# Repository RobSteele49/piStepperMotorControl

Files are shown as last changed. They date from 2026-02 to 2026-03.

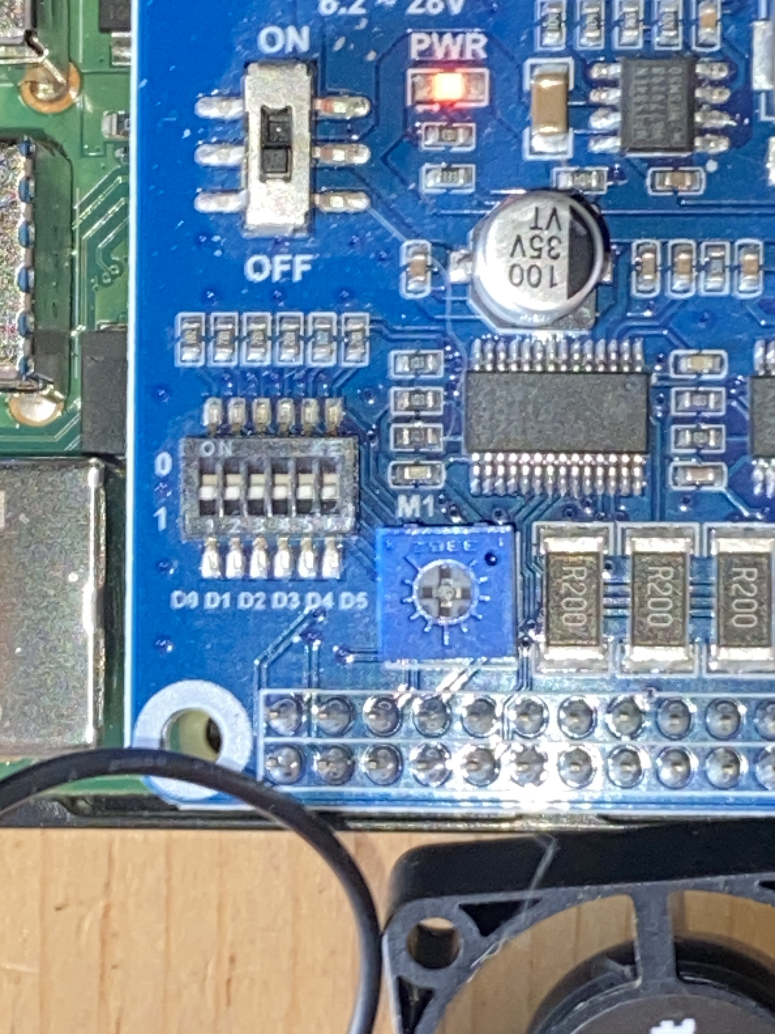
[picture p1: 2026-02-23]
photos/IMG_4501.JPG

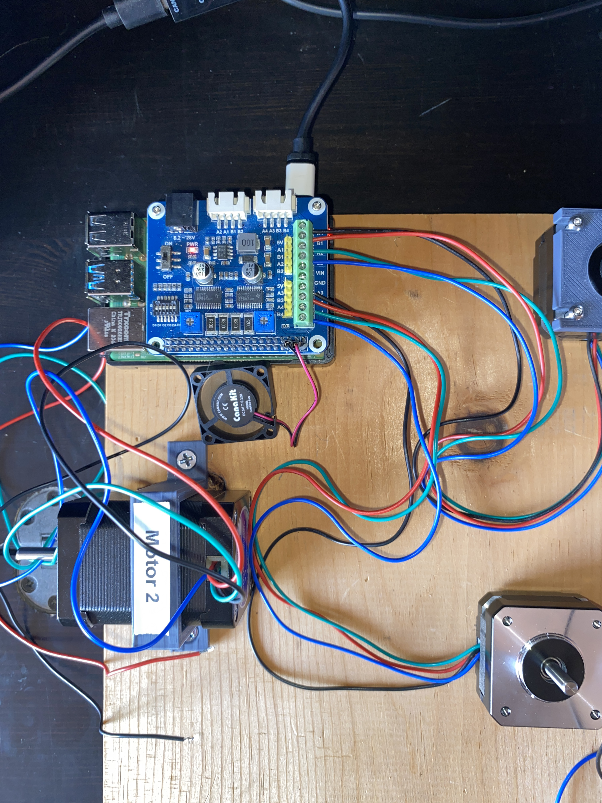
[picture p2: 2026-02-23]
photos/IMG_4499.JPG

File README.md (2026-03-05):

# piStepperMotorControl
Software for the controlling of steeper motors from a pi and pi hat.
Working software from across several directories will be placed here.

2026 03 05

Moved this document (and other project documents) into

- docs/ObsidianDocuments/ProjectDocuments to try and keep updated documents in a reasonable location.
- docs/ObsidianDocuments/Notes will be the home for notes before they get moved into more permanent locations or deleted.

2026 02 03

The code in this directory, with the DIP switches set to 1/16 step are working
for both motors are working.

The code provided by ChatGPT, which are NOT in this directory are NOT working.
I'm not sure why.

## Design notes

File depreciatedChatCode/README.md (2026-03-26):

Markdown
# piStepperMotorControl - LX200 Focuser & Rotator Automation

**Software for controlling stepper motors on a Raspberry Pi with LX200 protocol support and ASCOM Alpaca integration.**

This project provides automated control of focuser and rotator motors for telescope systems, featuring:
- **ASCOM Alpaca Server** for integration with astronomy software (NINA, etc.)
- **Physical button control** with speed ramping
- **Preset management** for saving/loading focus positions
- **Dual motor support** (focuser & rotator)
- **Watchdog protection** to prevent runaway motors
- **WaveShare stepper motor driver** support

---

## Table of Contents
- [Features](#features)
- [Hardware Requirements](#hardware-requirements)
- [Directory Structure](#directory-structure)
- [Installation](#installation)
- [Quick Start](#quick-start)
- [Architecture](#architecture)
- [Configuration](#configuration)
- [Usage](#usage)
- [Troubleshooting](#troubleshooting)
- [License](#license)

---

## Features

✅ **Dual Motor Control** - Independent focuser and rotator automation  
✅ **ASCOM Alpaca Protocol** - Seamless integration with NINA, APT, and other astronomy software  
✅ **Physical Button Interface** - 4-button control panel with speed ramping  
✅ **Preset Management** - Save and recall focus/rotator positions  
✅ **Safety Features** - Motor limits, watchdog timeout, emergency stop  
✅ **Network Accessible** - HTTP API on port 8080  
✅ **Low-Cost Hardware** - Uses standard Raspberry Pi and WaveShare stepper modules  

---

## Hardware Requirements

### Microcontroller
- **Raspberry Pi 3B+** or later (4B recommended for better performance)
- **Raspberry Pi OS** (Bullseye or later)

### Motor Control
- **2x WaveShare RS485 Stepper Motor Driver HAT** for each motor
- **2x NEMA17 Stepper Motors** (200 steps/rev)
- **Power Supply** - 12-24V @ 2A minimum per motor

### Physical Controls
- **4x Push Buttons** (momentary switches)
- **GPIO Pins**: 17, 27, 22, 23 (configurable in `config.h`)

### Wiring
Refer to the WaveShare motor driver documentation for GPIO pin mappings. The default configuration uses:
- GPIO 17: Focuser In
- GPIO 27: Focuser Out  
- GPIO 22: Rotator Clockwise
- GPIO 23: Rotator Counter-Clockwise

---

## Directory Structure

piStepperMotorControl/ ├── README.md # This file ├── CMakeLists.txt # CMake build configuration ├── include/ # Header files │ ├── AlpacaServer.hpp # ASCOM Alpaca HTTP server │ ├── WaveShareStepper.hpp # WaveShare driver interface │ └── config.h # System configuration constants ├── src/ # Source files │ ├── LX200_DualController.cpp # Main controller & UI │ ├── WaveShareStepper.cpp # Motor control implementation │ ├── AlpacaTest.cpp # Alpaca server test │ ├── HardwareProbe.cpp # Hardware diagnostics │ ├── testFocuser.cpp # Focuser unit tests │ ├── testRotator.cpp # Rotator unit tests │ └── httplib.h # HTTP library (header-only) ├── docs/ # Documentation │ ├── ObsidianDocuments/ # Project notes and specs │ └── ARCHITECTURE.md # (Coming soon) ├── photos/ # Hardware setup photos ├── CadFiles/ # 3D printing files for enclosure ├── build/ # Build output (auto-generated) └── CMakeLists.txt # Build configuration

Code

---

## Installation

### Prerequisites

1. **Update Raspberry Pi**
   ```bash
   sudo apt-get update
   sudo apt-get upgrade
Install Dependencies

bash
sudo apt-get install build-essential cmake git pigpio pigpio-tools
Enable I2C and SPI (required for WaveShare HAT)

bash
sudo raspi-config
# Navigate to Interface Options → I2C → Enable
# Navigate to Interface Options → SPI → Enable
Start pigpio daemon

bash
sudo systemctl enable pigpiod
sudo systemctl start pigpiod
Clone and Build
bash
# Clone the repository
git clone https://github.com/RobSteele49/piStepperMotorControl.git
cd piStepperMotorControl

# Create build directory
mkdir -p build
cd build

# Configure and compile
cmake ..
make

# Optional: Install to system
sudo make install
Quick Start
1. Configure Your Hardware
Edit include/config.h with your specific values:

C++
// Focuser travel range (steps)
const long long FOC_LIMIT_MIN = 0;
const long long FOC_LIMIT_MAX = 50000;

// Motor speeds (higher value = slower)
const int FOC_SPEED_MAX = 600;
const int FOC_SPEED_MED = 1200;
const int FOC_SPEED_SLOW = 2000;
2. Run the Controller
bash
cd build
./LX200_DualController
Output:

Code
=================== SYSTEM STATUS ======================
 FOCUSER: 25000 steps [50.0% Travel]
 ROTATOR: 0 steps [50.0% Travel]
 -------------------------------------------------------
 FOCUSER: [1-3] IN (0.1, 1, 5 Rev) | [4-6] OUT
 ROTATOR: [7] 1/16 CW | [8] 1/16 CCW
 PRESETS: [V] View/Apply | [K] Keep Current | [Y] Sync
 UTILS:   [G] GoTo  | [M] Move  | [R] Re-Seat | [L] Log
 POWER:   [U] Unlock Motors
 EXIT:    [P] Park & Log | [Q] Quit
3. Connect from NINA
Open NINA → Equipment → Add Device
Select Alpaca device type
Enter your Pi's IP address (default port 8080)
The "Dual Controller Focuser" and "Rotator" will appear
Architecture
Core Components
LX200_DualController (Main Controller)

Runs main event loop (50ms heartbeat)
Handles keyboard input, button presses, and menu navigation
Manages preset save/load
Coordinates with motor drivers
AlpacaServer (Network Interface)

Implements ASCOM Alpaca protocol over HTTP
Handles remote move commands from NINA, APT, etc.
Reports motor status (position, is_moving, etc.)
Runs in separate thread (port 8080)
WaveShareStepper (Motor Driver)

Interfaces with WaveShare RS485 HAT
Implements ramped acceleration/deceleration
Enforces soft limits (FOC_LIMIT_MIN/MAX, etc.)
Handles backlash compensation
Data Flow
Code
┌─────────────────────────────────────────────────────────┐
│         NINA / Astronomy Software                       │
│         (Remote Client)                                 │
└──────────────────────┬──────────────────────────────────┘
                       │ HTTP Requests
                       ▼
        ┌──────────────────────────────┐
        │   AlpacaServer (Thread)      │
        │   Port 8080                  │
        └──────────────┬───────────────┘
                       │
        ┌──────────────▼───────────────┐
        │  LX200_DualController        │
        │  Main Event Loop (50ms)      │
        └──────────┬──────────┬────────┘
                   │          │
        ┌──────────▼──┐  ┌────▼────────┐
        │  Focuser    │  │  Rotator    │
        │  WaveShare  │  │  WaveShare  │
        └─────────────┘  └─────────────┘
                   │          │
        ┌──────────▼──────────▼─┐
        │   GPIO / SPI / I2C    │
        │   Raspberry Pi HATs   │
        └───────────────────────┘
Session Logging
All motor movements are logged to night_log.txt:

Code
[2026-03-26 22:15] Foc:    25000 | Rot:        0
[2026-03-26 22:30] Foc:    30000 | Rot:      400
Configuration
Motor Speeds
Adjust these constants in config.h based on your motor and gearing:

C++
// Focuser (M1)
const int FOC_SPEED_MAX = 600;    // Fastest (600μs between steps)
const int FOC_SPEED_MED = 1200;   // Medium
const int FOC_SPEED_SLOW = 2000;  // Slowest

// Rotator (M2)
const int ROT_SPEED_MAX = 1600;
const int ROT_SPEED_MED = 2400;
const int ROT_SPEED_SLOW = 5000;
Lower values = faster motors. Adjust to prevent stalling.

Motor Limits
C++
// Focuser travel range
const long long FOC_LIMIT_MIN = 0;
const long long FOC_LIMIT_MAX = 50000;

// Rotator limits (prevents cable wrap)
const long long ROT_LIMIT_MIN = -6400;   // 2 full turns left
const long long ROT_LIMIT_MAX = 6400;    // 2 full turns right
Calibration
If your motor doesn't turn the expected distance:

Measure actual rotation: Run [K] (Keep Current) at a known position
Check STEPS_PER_KNOB_REV - currently calibrated for 5 turns → 6.75 turns
Recalibrate formula: STEPS_PER_KNOB_REV = (measured_steps / expected_steps) * current_value
Usage
Interactive Mode (Keyboard Control)
The program detects if it has a terminal and enters interactive mode:

Code
[1-3]  Move focuser IN  (0.1, 1.0, 5.0 revolutions)
[4-6]  Move focuser OUT
[7]    Rotate CW (1/16 turn)
[8]    Rotate CCW (1/16 turn)
[V]    View and apply presets
[K]    Keep current position as preset
[Y]    Sync motor to new position
[G]    Go to absolute position
[M]    Move by offset
[R]    Re-seat (backlash normalization)
[L]    View session log
[C]    Clear log
[U]    Unlock motors (release holding torque)
[P]    Park and exit
[Q]    Quit immediately
Physical Button Control
Press and hold buttons for adaptive speed:

< 2 seconds: Slow speed
> 2 seconds: Fast speed (ramping)
Service Mode (Background Operation)
If run without a terminal (e.g., from systemd):

bash
nohup ./LX200_DualController > /var/log/lx200.log 2>&1 &
The program will:

Skip the menu display
Still process physical buttons
Still respond to Alpaca network requests
Log all activity to night_log.txt
ASCOM Alpaca API
Available endpoints on http://<pi-ip>:8080:

Focuser Endpoints:

GET /api/v1/focuser/0/connected - Connection status
GET /api/v1/focuser/0/position - Current position
GET /api/v1/focuser/0/ismoving - Is motor moving?
PUT /api/v1/focuser/0/move?Position=<value> - Move to position
PUT /api/v1/focuser/0/halt - Stop immediately
Rotator Endpoints:

GET /api/v1/rotator/0/connected - Connection status
GET /api/v1/rotator/0/position - Current position
GET /api/v1/rotator/0/ismoving - Is motor moving?
PUT /api/v1/rotator/0/moveabsolute?Position=<value> - Move to position
PUT /api/v1/rotator/0/halt - Stop immediately
Troubleshooting
Motors Don't Move
 Check pigpiod is running: pgrep pigpiod
 Verify GPIO pins in config.h match your wiring
 Test with HardwareProbe utility
 Check motor power supply (12-24V)
 Ensure WaveShare HAT is properly connected
Alpaca Server Not Connecting
 Run from inside build/ directory
 Check firewall: sudo ufw allow 8080
 Verify Pi IP: hostname -I
 Test with browser: http://<pi-ip>:8080/management/v1/description
 Check network connectivity
Motors Skip Steps (Stalling)
 Reduce speed (increase delay value in config.h)
 Check power supply capacity
 Verify torque settings in WaveShare HAT DIP switches
 Check for mechanical binding
Position Drift
 Run [R] (Re-seat) to normalize backlash
 Check for loose gearing/belts
 Verify STEPS_PER_KNOB_REV calibration
 Check motor wiring for loose connections
Connection Timeout
 Increase watchdog timeout value in config.h
 Check system load with top
 Verify power supply under load
Development
Building Tests
bash
cd build
cmake -DBUILD_TESTS=ON ..
make
./testFocuser
./testRotator
Future Improvements
 Persistent position storage (EEPROM/database)
 Temperature monitoring
 Live position graphing
 Advanced backlash profiles
 Web UI dashboard
 Mobile app integration
License
© 2026 Robert D. Steele. All Rights Reserved.

Support
For issues, feature requests, or questions:

Check the Troubleshooting section
Review docs/ObsidianDocuments/ for detailed notes
Open an issue on GitHub
Last Updated: March 26, 2026
Version: 4.11

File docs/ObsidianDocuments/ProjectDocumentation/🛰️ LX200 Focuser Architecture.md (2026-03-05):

**Project:** Telescope Automation
**Platform:** Raspberry Pi + WaveShare Stepper HAT

## Component Breakdown
- **AlpacaServer.hpp:** The "Brain." Handles the ASCOM Alpaca REST API and translates network requests into motor commands.
- **WaveShareStepper.cpp/hpp:** The "Muscles." Low-level C++/pigpio code that manages step pulses, ramping, and power-save timeouts.
- **config.h:** The "Settings." Centralizes all hardware constants, speeds, and safety limits.
- **testFocuser.cpp:** The "Diagnostic." A standalone utility to verify mechanical calibration without needing ASCOM.

## Logic Flow
1. ASCOM (NINA) -> 2. REST API (Pi) -> 3. AlpacaServer -> 4. WaveShareStepper -> 5. GPIO Pulses -> 6. Motor

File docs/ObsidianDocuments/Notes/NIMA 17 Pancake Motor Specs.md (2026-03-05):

# Stepper Motor HAT for Raspberry Pi 4B/3B+/2B/B+/Zero/W/WH/and Jetson Nano,DRV8825 Motor Controller Drives Two Stepper Motors, Up to 1/32 Microstepping,Use for 3D Printer,Sculpturing Machine etc

| | |
|---|---|
|Brand|Bicool|
|Model Number|Stepper Motor HAT|
|Model Name|Stepper Motor HAT|
|Processor Brand|Broadcom|
|Video Processor|arm|
|UPC|779172279469|
|Manufacturer|Bicool|
|Best Sellers Rank|- #4,209 in [Single Board Computers (Computers & Accessories)](https://www.amazon.com/gp/bestsellers/pc/17441247011/ref=pd_zg_hrsr_pc)|
|ASIN|B08CCWDDQR|
|Customer Reviews|3.7 _3.7 out of 5 stars_   [(25)](https://www.amazon.com/dp/B08CCWDDQR?ref_=ppx_hzsearch_conn_dt_b_fed_asin_title_7#averageCustomerReviewsAnchor)|

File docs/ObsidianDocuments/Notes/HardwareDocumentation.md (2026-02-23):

**Computer Selection**

- Using a Raspberry Pi 4 for both the development and target environment.

**Motor Controller**

	- URL of Stepper Motor documentation:
		- https://www.waveshare.com/wiki/Stepper_Motor_HAT#Introduction
	- Additional pdf documentation available

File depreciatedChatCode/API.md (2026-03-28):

**Last Updated:** March 26, 2026  
**Version:** 1.0

Code

````

---

## **File 2: API.md**

```markdown
# ASCOM Alpaca API Reference

## Overview
The piStepperMotorControl system implements the ASCOM Alpaca protocol, enabling remote control from astronomy software like NINA, APT, SequenceGenerator Pro, and others.

## Connection Information

### Server Details
- **Host:** Your Raspberry Pi IP address (e.g., `192.168.1.100`)
- **Port:** `8080` (default)
- **Protocol:** HTTP
- **Base URL:** `http://<pi-ip>:8080`

### Finding Your Pi's IP Address
```bash
ssh pi@raspberrypi
hostname -I
````

Or from the Pi console:

bash

```
ip addr show | grep inet
```

---

## Management Endpoints

### Server Description

Returns information about the Alpaca server.

**Endpoint:**

Code

```
GET /management/v1/description
```

**Response:**

JSON

```
{
  "Value": {
    "ServerName": "Pi-LX200-Focuser",
    "Manufacturer": "Steele-Astronomy",
    "ManufacturerVersion": "1.1",
    "Location": "Observatory"
  },
  "ClientTransactionID": 0,
  "ServerTransactionID": 1,
  "ErrorNumber": 0,
  "ErrorMessage": ""
}
```

### Configured Devices

Returns list of available devices.

**Endpoint:**

Code

```
GET /management/v1/configureddevices
```

**Response:**

JSON

```
{
  "Value": [
    {
      "DeviceName": "Dual Controller Focuser",
      "DeviceType": "Focuser",
      "DeviceNumber": 0,
      "UniqueID": "Steele-Focuser-01"
    },
    {
      "DeviceName": "Dual Controller Rotator",
      "DeviceType": "Rotator",
      "DeviceNumber": 0,
      "UniqueID": "Steele-Rotator-01"
    }
  ],
  "ClientTransactionID": 0,
  "ServerTransactionID": 1,
  "ErrorNumber": 0,
  "ErrorMessage": ""
}
```

---

## Focuser Endpoints

### Connection Status

**Check if focuser is connected:**

Code

```
GET /api/v1/focuser/0/connected
PUT /api/v1/focuser/0/connected
```

**Parameters:** None for GET  
**PUT Body:** `Connected=true` or `Connected=false`

**Response:**

JSON

```
{
  "Value": true,
  "ClientTransactionID": 0,
  "ErrorNumber": 0,
  "ErrorMessage": ""
}
```

### Device Name

**Get focuser name:**

Code

```
GET /api/v1/focuser/0/name
```

**Response:**

JSON

```
{
  "Value": "Dual-Controller Focuser",
  "ClientTransactionID": 0,
  "ErrorNumber": 0,
  "ErrorMessage": ""
}
```

### Current Position

**Get current focuser position (in steps):**

Code

```
GET /api/v1/focuser/0/position
```

**Response:**

JSON

```
{
  "Value": 25000,
  "ClientTransactionID": 0,
  "ErrorNumber": 0,
  "ErrorMessage": ""
}
```

**Note:** Position is always in absolute steps from FOC_LIMIT_MIN.

### Movement Status

**Check if focuser is moving:**

Code

```
GET /api/v1/focuser/0/ismoving
```

**Response:**

JSON

```
{
  "Value": false,
  "ClientTransactionID": 0,
  "ErrorNumber": 0,
  "ErrorMessage": ""
}
```

Returns `true` while motor is moving, `false` when stationary.

### Absolute Position

**Check if focuser supports absolute positioning:**

Code

```
GET /api/v1/focuser/0/absolute
```

**Response:**

JSON

```
{
  "Value": true,
  "ClientTransactionID": 0,
  "ErrorNumber": 0,
  "ErrorMessage": ""
}
```

### Maximum Step Count

**Get maximum focuser position (max travel range):**

Code

```
GET /api/v1/focuser/0/maxstep
```

**Response:**

JSON

```
{
  "Value": 50000,
  "ClientTransactionID": 0,
  "ErrorNumber": 0,
  "ErrorMessage": ""
}
```

**Note:** This is set to `FOC_LIMIT_MAX` in config.h (typically 50000).

### Maximum Increment

**Get maximum single step distance:**

Code

```
GET /api/v1/focuser/0/maxincrement
```

**Response:**

JSON

```
{
  "Value": 5000,
  "ClientTransactionID": 0,
  "ErrorNumber": 0,
  "ErrorMessage": ""
}
```

**Note:** NINA uses this for safety checks. Adjustable in AlpacaServer.hpp.

### Move to Position

**Command focuser to absolute position:**

Code

```
PUT /api/v1/focuser/0/move
```

**Parameters:**

- `Position` (required) - Target position in steps (0 to 50000)
- `ClientTransactionID` (optional) - Tracking ID for your request

**Example:**

Code

```
PUT /api/v1/focuser/0/move?Position=30000&ClientTransactionID=1
```

**Response:**

JSON

```
{
  "ClientTransactionID": 1,
  "ErrorNumber": 0,
  "ErrorMessage": ""
}
```

**Important Notes:**

- Movement is asynchronous (returns immediately)
- Check `ismoving` endpoint to track completion
- Position will be clamped to FOC_LIMIT_MIN/MAX automatically

### Halt Movement

**Stop focuser immediately:**

Code

```
PUT /api/v1/focuser/0/halt
```

**Parameters:**

- `ClientTransactionID` (optional)

**Response:**

JSON

```
{
  "ClientTransactionID": 0,
  "ErrorNumber": 0,
  "ErrorMessage": ""
}
```

---

## Rotator Endpoints

### Connection Status

**Check if rotator is connected:**

Code

```
GET /api/v1/rotator/0/connected
PUT /api/v1/rotator/0/connected
```

**Response:** Same format as focuser

### Device Name

**Get rotator name:**

Code

```
GET /api/v1/rotator/0/name
```

**Response:**

JSON

```
{
  "Value": "Dual-Controller Rotator",
  "ClientTransactionID": 0,
  "ErrorNumber": 0,
  "ErrorMessage": ""
}
```

### Current Position

**Get current rotator position (in steps):**

Code

```
GET /api/v1/rotator/0/position
```

**Response:**

JSON

```
{
  "Value": 0,
  "ClientTransactionID": 0,
  "ErrorNumber": 0,
  "ErrorMessage": ""
}
```

**Note:** Position range is -6400 to +6400 steps (±2 full rotations).

### Movement Status

**Check if rotator is moving:**

Code

```
GET /api/v1/rotator/0/ismoving
```

**Response:** Same format as focuser

### Can Halt

**Check if rotator supports halt command:**

Code

```
GET /api/v1/rotator/0/canhalt
```

**Response:**

JSON

```
{
  "Value": true,
  "ClientTransactionID": 0,
  "ErrorNumber": 0,
  "ErrorMessage": ""
}
```

### Move to Absolute Position

**Command rotator to absolute angle:**

Code

```
PUT /api/v1/rotator/0/moveabsolute
```

**Parameters:**

- `Position` (required) - Target position in steps
- `ClientTransactionID` (optional)

**Example:**

Code

```
PUT /api/v1/rotator/0/moveabsolute?Position=1600&ClientTransactionID=2
```

**Response:**

JSON

```
{
  "ClientTransactionID": 2,
  "ErrorNumber": 0,
  "ErrorMessage": ""
}
```

**Important Notes:**

- Position will be clamped to ROT_LIMIT_MIN/MAX
- Movement is asynchronous
- 3200 steps = 1 full rotation

### Halt Movement

**Stop rotator immediately:**

Code

```
PUT /api/v1/rotator/0/halt
```

**Response:** Same format as focuser

---

## Integration Examples

### NINA (N.I.N.A.) Setup

1. **Open NINA Equipment Manager**
    
    - Go to Equipment → Add Device
    - Select "Alpaca" device type
    - Click "Search"
2. **Enter Connection Details**
    
    - Server: Your Pi's IP (e.g., 192.168.1.100)
    - Port: 8080
    - Click "Discover Devices"
3. **Select Devices**
    
    - Choose "Dual Controller Focuser"
    - Choose "Dual Controller Rotator"
    - Click "Add"
4. **Configure in NINA**
    
    - Set focuser as your active focuser
    - Set rotator as your active rotator
    - Configure autofocus settings

### Manual API Testing (cURL)

**Test connection:**

bash

```
curl http://192.168.1.100:8080/management/v1/description
```

**Move focuser to position 30000:**

bash

```
curl -X PUT "http://192.168.1.100:8080/api/v1/focuser/0/move?Position=30000"
```

**Get current focuser position:**

bash

```
curl http://192.168.1.100:8080/api/v1/focuser/0/position
```

**Rotate to 45 degrees (1/8 turn = 400 steps):**

bash

```
curl -X PUT "http://192.168.1.100:8080/api/v1/rotator/0/moveabsolute?Position=400"
```

**Stop all movement:**

bash

```
curl -X PUT http://192.168.1.100:8080/api/v1/focuser/0/halt
curl -X PUT http://192.168.1.100:8080/api/v1/rotator/0/halt
```

### Python Example

Python

```
import requests
import time

PI_IP = "192.168.1.100"
BASE_URL = f"http://{PI_IP}:8080"

# Move focuser to position 30000
response = requests.put(
    f"{BASE_URL}/api/v1/focuser/0/move",
    params={"Position": 30000}
)
print(f"Focuser move response: {response.json()}")

# Wait for movement to complete
while True:
    moving_response = requests.get(
        f"{BASE_URL}/api/v1/focuser/0/ismoving"
    )
    if not moving_response.json()["Value"]:
        break
    print("Moving...")
    time.sleep(0.5)

# Get final position
position_response = requests.get(
    f"{BASE_URL}/api/v1/focuser/0/position"
)
print(f"Final position: {position_response.json()['Value']}")

# Rotate
requests.put(
    f"{BASE_URL}/api/v1/rotator/0/moveabsolute",
    params={"Position": 1600}
)
```

---

## Error Handling

### Error Response Format

JSON

```
{
  "ClientTransactionID": 1,
  "ErrorNumber": 1,
  "ErrorMessage": "Position out of range"
}
```

### Common Error Codes

- **0** - No error
- **1** - Invalid parameter
- **2** - Device not connected
- **3** - Position out of range
- **999** - Driver error

### Error Scenarios

**Position out of range:**

- Attempting to move beyond FOC_LIMIT_MIN/MAX or ROT_LIMIT_MIN/MAX
- System automatically clamps to valid range

**Device not connected:**

- Motor driver not responding
- Check power supply and wiring
- Verify pigpiod daemon is running

---

## Response Format Specification

All responses follow ASCOM Alpaca standard:

JSON

```
{
  "Value": <any>,                    // Response data (varies by endpoint)
  "ClientTransactionID": <number>,   // Echo of client's request ID
  "ServerTransactionID": <number>,   // Server's transaction sequence
  "ErrorNumber": <number>,           // 0 = success, non-zero = error
  "ErrorMessage": "<string>"         // Error description (empty if success)
}
```

---

## Performance Characteristics

### Response Times

- **Status queries** (position, ismoving): < 50ms
- **Move commands** (async): < 100ms
- **Network latency** (local network): 1-10ms

### Movement Profiles

- **Typical focus move** (10,000 steps): 3-5 seconds
- **Full rotation** (3200 steps): 2-4 seconds
- **Speed adjustable** via config.h

### Concurrent Requests

- Focuser and rotator can move simultaneously
- Each has independent movement queue
- Requests are processed in order

---

## Debugging & Testing

### Test Server Availability

bash

```
curl -v http://<pi-ip>:8080/management/v1/description
```

### Monitor Real-Time Logs

bash

```
ssh pi@raspberrypi
tail -f night_log.txt
```

### Enable Debug Output

In `AlpacaServer.hpp`, uncomment debug statements:

C++

```
std::cout << "[NET] Focuser Move Threaded -> " << target << std::endl;
```

---

## Best Practices

1. **Always check `ismoving` before issuing new commands**
    
    Python
    
    ```
    while requests.get(f"{BASE_URL}/api/v1/focuser/0/ismoving").json()["Value"]:
        time.sleep(0.1)
    ```
    
2. **Use reasonable position increments**
    
    - Large jumps (> 10000 steps) risk mechanical shock
    - Use MaxIncrement (5000 steps) as guidance
3. **Implement connection retry logic**
    
    Python
    
    ```
    import time
    for attempt in range(3):
        try:
            response = requests.get(f"{BASE_URL}/management/v1/description", timeout=2)
            if response.status_code == 200:
                break
        except:
            time.sleep(1)
    ```
    
4. **Log all movements for troubleshooting**
    
    - Check `night_log.txt` on the Pi
    - Correlate with your observation timeline
5. **Halt before critical operations**
    
    Python
    
    ```
    requests.put(f"{BASE_URL}/api/v1/focuser/0/halt")
    requests.put(f"{BASE_URL}/api/v1/rotator/0/halt")
    time.sleep(0.5)
    ```

---

## Limitations & Known Issues

- Movement is asynchronous (no blocking calls)
- No intermediate position updates during movement
- No acceleration/deceleration feedback
- Position accuracy depends on STEPS_PER_KNOB_REV calibration
- Network timeout if Pi loses power/connectivity

---

## Troubleshooting

### "Connection refused" on port 8080

- Verify Pi is running and network is available
- Check firewall: `sudo ufw allow 8080`
- Restart service: `pkill LX200_DualController`

### NINA can't discover devices

- Ensure Alpaca server is running
- Verify IP address and port are correct
- Check that Pi is on same network as NINA machine

### Movements are very slow

- Check config.h motor speed settings
- Verify power supply is adequate (12-24V @ 2A)
- Run calibration test

### Position doesn't reach target

- Verify position is within limits
- Check for mechanical binding
- Run re-seat operation via CLI: `[R]`

---

## API Changelog

### Version 3.0 (Current)

- Full ASCOM Alpaca protocol support
- Improved connection handshaking
- MaxStep and MaxIncrement endpoints
- Better error handling

### Version 2.0

- Basic HTTP server
- Core move commands

### Version 1.0

- Initial release

---

## Additional Resources

- [ASCOM Alpaca Specification](https://ascom-standards.org/Help/Platform/html/T_ASCOM_Alpaca_Discovery.htm)
- [NINA Documentation](https://nighttime-imaging.eu/)
- Project README: [README.md](https://github.com/README.md)
- Configuration Guide: [CONFIGURATION.md](https://github.com/copilot/c/CONFIGURATION.md)

---

**Last Updated:** March 26, 2026  
**API Version:** 3.0  
**Server Version:** 4.11

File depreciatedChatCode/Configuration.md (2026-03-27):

````
# Configuration Guide

## Overview
This guide provides detailed information on configuring the piStepperMotorControl system for your specific telescope setup and hardware.

## Configuration File Location
All configuration constants are defined in: `include/config.h`

---

## Hardware Settings

### Microstepping Configuration
```cpp
const int STEPS_PER_REV = 3200;         // 200 * 16 (1/16 microstepping)
const int DEFAULT_RAMP_MS = 800;        // Default ramp time in milliseconds
const int STEPS_PER_KNOB_REV = 2480;    // Calibrated steps per physical revolution
````

**Note:** The `STEPS_PER_KNOB_REV` value is calibrated for your specific gearing. The current value assumes 5 commanded turns result in 6.75 actual turns. Adjust this if your motor behavior differs.

---

## Focuser Configuration

### Travel Limits

C++

```
const long long FOC_LIMIT_MIN = 0;           // Minimum position (steps)
const long long FOC_LIMIT_MAX = 50000;       // Maximum position (steps)
```

**How to Set:**

1. Manually move your focuser to the closest focus position
2. Record the position value shown in the UI
3. Set `FOC_LIMIT_MIN` to this value
4. Move to the furthest focus position
5. Set `FOC_LIMIT_MAX` to this value
6. Recompile with `cmake .. && make`

### Motor Speed Configuration

C++

```
// FOCUSER (M1) - Delays in microseconds between steps
const int FOC_SPEED_MAX = 600;          // Fastest (less delay = faster)
const int FOC_SPEED_MED = 1200;         // Medium speed
const int FOC_SPEED_SLOW = 2000;        // Slowest (more delay = slower)
const int FOC_BACKLASH = 600;           // Backlash compensation (steps)
const int FOC_PREF_DIR = 0;             // Preferred direction (0=CCW, 1=CW)
```

**Speed Tuning Guide:**

- **Speed value** = delay in microseconds between motor steps
- **Smaller value** = Motor moves faster (shorter delays)
- **Larger value** = Motor moves slower (longer delays)
- **Recommended range:** 500-3000

**If motor stalls:**

- Increase the speed value (e.g., FOC_SPEED_MAX from 600 to 800)
- Check power supply voltage under load
- Verify motor wiring

**If motor moves too slowly:**

- Decrease the speed value (e.g., FOC_SPEED_MED from 1200 to 1000)
- Ensure power supply can deliver full current

### Backlash Compensation

C++

```
const int FOC_BACKLASH = 600;           // Steps to overshoot and return
```

The backlash compensation works by:

1. Moving beyond target by `FOC_BACKLASH` steps
2. Moving backward to actual target
3. Eliminates gear slack

**Tuning:**

- If focus still drifts: increase value (try 800-1000)
- If overshoot causes issues: decrease value (try 400-500)

---

## Rotator Configuration

### Travel Limits

C++

```
const long long ROT_LIMIT_MIN = -6400;   // 2 full turns left (prevents cable wrap)
const long long ROT_LIMIT_MAX = 6400;    // 2 full turns right
```

**Why these limits?**

- Prevents cable tangling
- Limits continuous rotation to ±2 full turns
- Adjust based on your cable management setup

### Motor Speed Configuration

C++

```
// ROTATOR (M2) - Delays in microseconds between steps
const int ROT_SPEED_MAX = 1600;         // Fastest
const int ROT_SPEED_MED = 2400;         // Medium speed
const int ROT_SPEED_SLOW = 5000;        // Slowest
const int ROT_BACKLASH = 200;           // Backlash compensation (steps)
const int ROT_PREF_DIR = 1;             // Preferred direction (0=CCW, 1=CW)
```

**Note:** Rotator speeds are slower than focuser because rotation is more critical for precision. Fine adjustments may be needed for your specific camera/filter setup.

---

## Button Control Configuration

### GPIO Pin Assignment

C++

```
// BUTTON BOX PINS (GPIO Numbers on Raspberry Pi)
const int BTN_FOC_IN = 17;      // Focuser move IN (toward scope)
const int BTN_FOC_OUT = 27;     // Focuser move OUT (away from scope)
const int BTN_ROT_CW = 22;      // Rotator Clockwise
const int BTN_ROT_CCW = 23;     // Rotator Counter-Clockwise
```

**GPIO Pin to Physical Pin Mapping:**

Code

```
GPIO 17 → Pin 11
GPIO 27 → Pin 13
GPIO 22 → Pin 15
GPIO 23 → Pin 16
```

### Speed Ramping Configuration

C++

```
const double RAMP_THRESHOLD_SEC = 2.0;  // Seconds before switching to high speed
```

**How it works:**

- **Button pressed < 2 seconds:** Uses SLOW speed setting
- **Button held > 2 seconds:** Switches to MAX speed setting
- **Adjustment:** Change 2.0 to different value (e.g., 1.5 or 3.0) for different threshold

---

## Re-seating (Backlash Normalization)

### Configuration

C++

```
#define RESEAT_GAP_STEPS 1000  // Distance to move for backlash elimination
```

**What is Re-seating?**

- Moves motor forward by `RESEAT_GAP_STEPS`
- Then moves back to original position
- Eliminates accumulated backlash

**When to use:**

- After initial setup
- Before important observations
- If you notice position drift
- Press `[R]` in interactive mode

**Tuning `RESEAT_GAP_STEPS`:**

- **Too small (< 500):** Doesn't eliminate backlash effectively
- **Too large (> 2000):** Time-consuming and unnecessary
- **Recommended:** 800-1200 for focuser, 400-800 for rotator

---

## Motor Calibration

### STEPS_PER_KNOB_REV Calculation

This value represents how many steps are needed for one physical revolution of your knob/gearing.

**Calibration Procedure:**

1. **Initial Measurement:**
    
    C++
    
    ```
    const int STEPS_PER_KNOB_REV = 2480;  // Current value
    ```
    
2. **Command Test Movement:**
    
    - Use menu option `[K]` to record starting position
    - Then move using menu option `[1]` (0.1 revolution)
    - Note the steps moved
3. **Calculate Actual Ratio:**
    
    Code
    
    ```
    Expected steps = 2480 * 0.1 = 248 steps
    If actual moved = 300 steps:
    New STEPS_PER_KNOB_REV = 2480 * (300/248) = 3000
    ```
    
4. **Update and Recompile:**
    
    C++
    
    ```
    const int STEPS_PER_KNOB_REV = 3000;  // Updated value
    ```
    
    Then: `cd build && cmake .. && make`

### Mechanical Calibration Checklist

- [ ]  Verify motor is mechanically coupled to focuser
- [ ]  Check for loose belts or gears
- [ ]  Test smooth motion in both directions
- [ ]  Verify power supply voltage: 12-24V DC
- [ ]  Check motor wiring for corrosion

---

## Advanced Configuration

### Preset Management

Presets are automatically saved to `presets.txt` in the working directory.

**Preset Format:**

Code

```
PresetName1 position_focuser position_rotator
PresetName2 position_focuser position_rotator
```

**Example:**

Code

```
Sharp 25000 0
SlightlyOut 27000 0
Rotated45deg 25000 1600
```

### Session Logging

All motor movements are logged to `night_log.txt`:

Code

```
[2026-03-26 22:15] Foc:    25000 | Rot:        0
[2026-03-26 22:30] Foc:    30000 | Rot:      400
[2026-03-26 22:45] Foc:    28500 | Rot:      400
```

To clear logs, press `[C]` in interactive mode.

---

## Recommended Configuration Examples

### Example 1: Refractor Scope (Slow, Precise Movement)

C++

```
// Use slower speeds for fine adjustments
const int FOC_SPEED_MAX = 1000;
const int FOC_SPEED_MED = 1500;
const int FOC_SPEED_SLOW = 2500;

// Increase backlash compensation
const int FOC_BACKLASH = 800;
```

### Example 2: Newtonian Reflector (Fast Movement)

C++

```
// Use faster speeds for quick adjustments
const int FOC_SPEED_MAX = 400;
const int FOC_SPEED_MED = 800;
const int FOC_SPEED_SLOW = 1500;

// Smaller backlash compensation
const int FOC_BACKLASH = 400;
```

### Example 3: Large Dobsonian (High Backlash)

C++

```
// Compensate for mechanical slack
const int FOC_BACKLASH = 1200;
const int RESEAT_GAP_STEPS = 1500;

// Slower, controlled movement
const int FOC_SPEED_MAX = 800;
const int FOC_SPEED_MED = 1200;
```

---

## Testing Configuration Changes

After modifying `config.h`:

bash

```
cd build
cmake ..
make
./LX200_DualController
```

**Functional Tests:**

1. Press `[1]` - Verify focuser moves IN the expected distance
2. Press `[7]` - Verify rotator moves CW smoothly
3. Press `[K]` - Save current position as preset
4. Press `[V]` - Retrieve and verify preset
5. Press `[R]` - Run re-seating operation

---

## Troubleshooting Configuration

### Problem: Motor Stalls During Movement

**Solution:**

- Increase speed value (e.g., FOC_SPEED_MAX: 600 → 800)
- Check power supply: should be 12-24V @ 2A min
- Verify motor wiring is secure
- Test with HardwareProbe utility

### Problem: Motor Overshoots Target Position

**Solution:**

- Decrease speed value (e.g., FOC_SPEED_MAX: 600 → 400)
- Increase backlash value (FOC_BACKLASH: 600 → 800)
- Run re-seating more frequently

### Problem: Position Drifts Over Time

**Solution:**

- Run re-seating: Press `[R]` periodically
- Increase backlash compensation
- Check for mechanical issues (loose gears, belts)
- Recalibrate STEPS_PER_KNOB_REV

### Problem: Buttons Don't Respond

**Solution:**

- Verify GPIO pins match physical wiring
- Check pull-up resistors on button circuit
- Test with `HardwareProbe` utility
- Check pigpiod is running: `pgrep pigpiod`

---

## Safety Considerations

### Motor Limits

The soft limits prevent mechanical damage:

C++

```
const long long FOC_LIMIT_MIN = 0;
const long long FOC_LIMIT_MAX = 50000;
```

**Always:**

- Set realistic limits for your hardware
- Test limits before nighttime observing
- Verify motors stop at boundaries

### Watchdog Timeout

Motors automatically cut power after 30 seconds of no movement (safety feature). No configuration needed.

### Emergency Stop

Press `Ctrl+C` at any time to emergency stop all motors and exit cleanly.

---

## Configuration Checklist

Before your first night of observing:

- [ ]  Updated `FOC_LIMIT_MIN` and `FOC_LIMIT_MAX`
- [ ]  Updated `ROT_LIMIT_MIN` and `ROT_LIMIT_MAX`
- [ ]  Calibrated `STEPS_PER_KNOB_REV`
- [ ]  Tested all 4 button functions
- [ ]  Saved at least one preset
- [ ]  Verified NINA can connect via Alpaca
- [ ]  Run re-seating test: `[R]`
- [ ]  Confirmed `night_log.txt` is being created
- [ ]  Tested all speed settings work
- [ ]  Created backup of your `config.h`

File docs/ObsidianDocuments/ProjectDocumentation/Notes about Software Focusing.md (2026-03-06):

2026 03 05

For the LX200 10" Classic

Clockwise (CW):
- This moves the primary mirror Rearward (toward the back of the scope).
- This pulls the focal point inward.
Counter-Clockwise (CCW):
- This moves the primary mirror Forward (toward the corrector plate/front of the scope).
Park the Mirror
- For a telescope not in use, the general consensus among SCT experts is to store the mirror in the Rearward position.

ASCOM Device Hub
- MOVE OUT
	- Moves focuser clockwise (CW)
	- Increment steps
- MOVE IN
	- Moves focuser counter-clockwise (CCW)
	- Decrement steps

NINA Focuser
- '>>'
	- Moves focuser clockwise (CW)
	- Increment steps
- '<<'
	- Moves focuser counter-clockwise (CCW)
	- Decrement steps

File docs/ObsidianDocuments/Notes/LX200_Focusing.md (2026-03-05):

Navigating the mechanical quirks of a classic Meade LX200 10" SCT is a bit of a rite of passage for amateur astronomers. Since you're mounted on a CGEM, you’ve already bypassed the old electronics issues, but the mirror mechanics remain the same.

Here is the breakdown of that focusing knob from your perspective (standing at the back of the tube, looking toward the sky).

Mirror Direction & Movement
On the LX200 Classic, the focus knob moves the primary mirror along a central baffle tube.

Counter-Clockwise (CCW): This moves the primary mirror Forward (toward the corrector plate/front of the scope). This pushes the focal point further back, which is helpful if you are using a long imaging train or a large 2" diagonal.

Clockwise (CW): This moves the primary mirror Rearward (toward the back of the scope). This pulls the focal point inward.

Reaching the Limits
Maximum Forward: Rotate the knob Counter-Clockwise until you feel gentle resistance.

Maximum Rearward: Rotate the knob Clockwise until you feel gentle resistance.

Pro-Tip: Never "torque" the knob when you hit the end of the travel. The LX200 uses a relatively simple threaded rod and pin system; forcing it can cause the mirror to bind or tilt unnecessarily.

Storage: Where to "Park" the Mirror?
For a telescope not in use, the general consensus among SCT experts is to store the mirror in the Rearward position.

Turn the knob Clockwise until the mirror is retracted toward the back of the cell.

Why? This keeps the primary mirror seated as low as possible on the baffle tube. It minimizes the risk of "mirror flop" during transport and reduces the amount of exposed, lubricated baffle tube that can collect dust or off-gas onto the optics over time.

A Note on Your CGEM Setup
Since you are using a German Equatorial Mount (GEM) instead of the original forks, your scope will undergo much more radical orientation changes (meridian flips).

The Golden Rule: Always finish your focus with a Counter-Clockwise turn. This pushes the mirror up against gravity. If you finish with a clockwise turn, gravity can cause the mirror to settle slightly later, ruining your focus or causing "shift" during a long exposure.

2026 03 05 Notes about Software Focusing

Clockwise (CW):
- This moves the primary mirror Rearward (toward the back of the scope).
- This pulls the focal point inward.
Counter-Clockwise (CCW):
- This moves the primary mirror Forward (toward the corrector plate/front of the scope).
Park the Mirror
- For a telescope not in use, the general consensus among SCT experts is to store the mirror in the Rearward position.

ASCOM Device Hub
- MOVE OUT
	- Moves focuser clockwise (CW)
	- Increment steps
- MOVE IN
	- Moves focuser counter-clockwise (CCW)
	- Decrement steps

NINA Focuser
- '>>'
	- Moves focuser clockwise (CW)
	- Increment steps
- '<<'
	- Moves focuser counter-clockwise (CCW)
	- Decrement steps

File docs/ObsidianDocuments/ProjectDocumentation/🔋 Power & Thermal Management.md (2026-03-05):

Pancake motors are prone to overheating. The system implements a **30-second Auto-Release** safety.

## The Logic (`checkTimeout`)
1. Whenever a motor moves, `_lastActivity` is updated.
2. If `30 seconds` pass without a new command, the `EN` (Enable) pin is set to `0` (Off).
3. This releases the "Holding Torque," allowing the motor to cool down.
4. The motor is automatically re-engaged (Powered) the moment a new `moveTo` command arrives.

> [!WARNING]
> If the telescope is pointing at the Zenith (straight up), releasing power might cause a heavy imaging train to "slip" or "creep." Monitor for focus drift during long sessions.

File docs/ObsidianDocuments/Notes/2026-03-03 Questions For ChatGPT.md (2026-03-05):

I am working on a focusers/rotator for my 10" LX200 optical tube that is mounted on a Celestron CGEM Equatorial mount. My long term goal is to run the telescope remotely via the NINA interface. I have miniPC mounted to the telescope along with a Raspberry Pi 4. The scope is mounted about 50 feet from the house with 110 power and a wifi extender connected to my Starlink router at the house.

I've got the software with the help of Gemini working and is in a repository https://github.com/RobSteele49/piStepperMotorControl
As this is a public accessible github repository I was told you could view the code. As of right now the code to move the focuser is working and I can control the focuser from an ASCOM Device Hub or NINA either wired directly between my mini PC and the Raspberry Pi 4 or via a WiFi connection. The Pi4 has a Stepper Hat which is working quite well. I'm using two NIMA 17 pancake motors.  I'm still bench testing but getting very close to moving outside. A few items I'd like to work on would include:

- Getting the code documented.
- Building a button interface. My goal is to have two buttons dedicated to the focusers and two dedicated to the camera rotator.
	- Focuser
		- For the focuser I was going to have one button dedicated to clockwise rotation and the other to counter-clockwise rotation.
		- If the button is held for <3 seconds it will move 'very' slowing between 3 and 6 seconds it will spend up to 1 rotation in 3 seconds, and if held greater than 6 seconds it will spend up to 1 rotation per second. (These are approximate and I'm hoping you can make some suggestions to improve things)
		- For the rotator I was thinking that if held <3 seconds it would be 'very' slowing and if > 3 seconds if would move at the rate of 1 rotation in 6 seconds. The maximum rotation allowed would be 180 degrees so I don't get cables wrapped up.
		- I would want to 3d print a button control box that would have cables connected to the raspberry pi and would have a spot to stay at the telescope.
	- Rotator
		- I have basic control working of this motor but not from NINA
		- I've started on a design but this will wait until I have button control working.
	- Button Control
		- I'm not very familiar with setting up button i/f on the Raspberry Pi 4 so I'm hoping for your help.
		- The buttons I'm planning on using were purchased from Amazon are are "# 5pcs 12mm 2A 12V/24V/125V/250V AC Prewired Waterproof Push Button Momentary Stainless Steel Push Button On Off (High Head)"
		- I don't have a box designed yet, so if you could create a openSCAD design of one that meets my requirements that would be a great help.
		- I do have the ability to take an openSCAD design and print it and/or use FreeCAD to turn it into a STEP file and make edits on the part wit onShape.

So getting the code documented, a button case, instructions for how to connect the buttons, along with the software would really help.

As I have working code in my repository I want to be very careful to not break it. Would using the pull mechanism and/or creating a fork be the safest way to to this work? If has been several years since I used GitHub for any serious development so I feel like I'm getting my feet wet.

Initial response from ChatGPT:

Rob — this is a very solid project description. Clear goal, real constraints, and you’re thinking about failure modes (cable wrap). Good engineering instincts.

Before I suggest improvements, I’m going to tighten this into a structured system view and then ask you the **right missing questions**. These are the kinds of things that determine whether this becomes “works” or “rock solid observatory-grade.”

---

# 🔭 System Summary (What I Understand)

**Optics:** 10" Meade LX200 Classic OTA  
**Mount:** Celestron CGEM  
**Imaging Software:** NINA  
**Control Hub:** ASCOM Device Hub  
**Compute:**

- MiniPC on scope (runs NINA)
    
- Raspberry Pi 4 (motor control)
    
- WiFi via Starlink + extender
    
- 110VAC at pier

**Motors:**

- 2 × NEMA 17 pancake steppers
    
- Stepper HAT on Pi
    
- Focuser working via ASCOM
    
- Rotator partially working

**Next goals:**

1. Code documentation
    
2. Physical button interface (4 buttons total)
    
3. 3D printed control box
    
4. Safe Git workflow
    
5. Avoid breaking working code

---

# 🔎 Important Missing Questions

These matter more than they look.

---

## 1️⃣ Absolute vs Relative Positioning

Does your focuser:

- Keep absolute position across power cycles?
    
- Or is it relative-only?

If power drops mid-session (Starlink hiccup, breaker trip), what happens?

For a rotator especially, **absolute position matters**.

Do you have:

- Limit switches?
    
- Home switch?
    
- Encoder?
    
- Or purely open-loop step counting?

---

## 2️⃣ Mechanical Reduction

What’s your gear ratio between motor and focuser shaft?

At 1 rotation/sec:

- Is that actually safe for the mechanics?
    
- Or will you induce vibration into the imaging train?

Astro reality: you rarely need high speed at the scope.

---

## 3️⃣ Microstepping

What microstep setting are you using on the Stepper HAT?

Earlier you mentioned 1/32 for precision. For focusing on an LX200:

- Depth of focus at f/10 is fairly forgiving.
    
- Torque margin matters more than resolution.

You might be over-optimizing precision and losing torque.

---

## 4️⃣ Cable Wrap Strategy (Rotator)

You said max 180°.

But what happens if:

- NINA rotates 170°
    
- Then user hits manual button 30°?

Will you:

- Track cumulative angle?
    
- Enforce hard limits in software?
    
- Or just “hope”?

This needs a state machine.

---

## 5️⃣ Button Control Philosophy

Your time-based speed tiers (<3s, 3–6s, >6s) are clever — but slightly brittle.

Better approach:

### Option A – Acceleration Ramp (Better UX)

Instead of time buckets:

- When button pressed → start slow
    
- Every 300ms increase speed
    
- Cap at max speed
    
- When released → decelerate

This feels much more natural.

Time buckets feel artificial.

---

## 6️⃣ Electrical Interface for Buttons

Those stainless momentary buttons:

Are they:

- NO (Normally Open)?
    
- With LED ring?
    
- What voltage is the LED rated for?

Very important:  
Pi GPIO is **3.3V only**.

We must:

- Use internal pull-ups
    
- Or external resistors
    
- Or opto-isolate (if long cable runs)

How long will the cable from box to Pi be?

50 feet? 2 feet?

Long runs = noise risk (especially near steppers).

---

## 7️⃣ Real Observatory Question

Is this system:

- Used only while you're present?
    
- Or truly unattended remote?

Because unattended changes everything:

- Watchdog
    
- Logging
    
- Motor stall detection
    
- Safe reboot state

---

# 🧠 Architectural Recommendation

You’re at the exact point where architecture matters.

I recommend separating:

```
MotorControl Layer
    ↓
Device Logic Layer (Focuser / Rotator state machines)
    ↓
Interface Layer
    - ASCOM
    - Buttons
    - Network
```

Buttons should NOT directly drive motors.

They should issue high-level commands:

```
focuser.move(direction, speed_profile)
```

That prevents breaking your working ASCOM interface.

---

# 🧰 Git Strategy (Very Important)

You asked:

> Should I fork? Pull? What's safest?

Since this is your repo:

### Best practice:

On Pi:

```bash
git checkout -b feature/button-interface
```

Work there.

When stable:

```bash
git checkout main
git merge feature/button-interface
```

Then push.

You do NOT need a fork.

Forking is for working on someone else’s repository.

---

# 🧩 OpenSCAD Box

Before I design it, I need:

- Button diameter (12mm mounting hole confirmed?)
    
- Panel thickness recommendation?
    
- Cable gland or strain relief?
    
- Size constraints?
    
- Weatherproof level?

You mentioned waterproof buttons — is the enclosure outdoors permanently?

---

# 🚀 What I Suggest Next

Let’s do this in phases:

Phase 1 – Lock Architecture  
Phase 2 – GPIO wiring design  
Phase 3 – Button speed control algorithm  
Phase 4 – OpenSCAD enclosure  
Phase 5 – Code documentation structure  
Phase 6 – Git workflow cleanup

---

# The 5 Questions I Need Answered First

1. Do you have any limit switches or encoders?
    
2. What microstepping setting are you currently using?
    
3. How long will the button cable run be?
    
4. Are the buttons illuminated?
    
5. Is this unattended or supervised operation?

Answer those and we’ll tighten this intoThe a professional-grade design.

You’re very close to something really nice here.

---
Answers:

Absolute vs. Relative Positioning
- For both focuser and rotational I've been looking at relative position
	- open loop with step counter
	- The telescope is operated while I'm in the living room, about 50' away. If power goes out I'll just go out and check on it
Mechanical reduction
- The motor has a 20 tooth timing belt and the focus knob is a smooth 60 tooth timing belt equivalence.
	- Smooth so that it can slip easily if it gets jammed
Micro stepping
- Using 1/16 microsteps. That was recommended as a good middle ground and a good place to start for focusing.
Cable Wrap
- For the focuser I only have to be concerned with the minimum and maximum positions, which is approximately 40 rotations
- For the rotation of the camera going over 30 degrees over the 180 would be OK. To be honest I have not spent much time thinking about this.
- Hard limits will be enforced in software
Button Control
- Option A looks really nice
Electrical I/F for Buttons
- 2 wires per button
- From Amazon
	-Product Description:  
	* Color: Silver  
	* Head Shape: high head  
	* Operation Type: Momentary  
	* Push buttons hole diameter: 12mm  
	* Push buttons hole thread: 0.75mm  
	* Switch Max Rating: 2A/12V/24V/125V/250VAC  
	* Material: nickel plated brass stainless steel  
	* These switches come with a rubber O-ring which makes them splash resistant but they can NOT be submerged in the water.
* No LED's so I'll be operating by feel
* Short cable, less than 1 meter
* I don't know how best to use buttons, but if there are better ones to buy I can do that
* See photos
Observation Questions:
- Only use when I'm not home
- Covered with a outdoor rated cover
- Because of the cold weather I normally keep the computers and even the telscope powered on. The temperature in Frazier Park, CA varies between 0 degree F to about 95 degrees F.
- I even keep a camera to watch cables
Architecture
- Buttons should only i/f with the software
- My Pi4 s/w is using the Alpaca i/f
Git
- I like the checkout/merge/push paradigm
OpenSCAD Box
- 12 mm mounting hold
- <2 mm panel thickness
- No bigger than necessary for 4 buttons
- Weather resistant
Question Answers
- No limit switches or encoders planned for right no
- Starting with 1/16 microsteps
- Cable for buttons around 1 meter
- Will run the telescope from the living room - about 50 feet (maybe a little less)

--------------
From ChatGPT

Excellent. This is now detailed enough to move from “concept” to solid engineering decisions.

You’re thinking clearly — but there are a few areas where tightening things now will save you headaches later.

---

# 🔍 Key Observations & Improvements

## 1️⃣ Open Loop + No Limits = Manageable (But Needs Discipline)

You’re running:

- Open-loop
    
- Step counter
    
- No limit switches
    
- No encoders
    
- 40 rotation travel on focuser
    
- ~180° rotator limit

Given that you're **supervised (living room, not 500 miles away)** this is acceptable.

But you _must_ implement:

### Required Safeguards

For focuser:

- Software min_position
    
- Software max_position
    
- Refuse moves outside bounds
    
- Persist last known position to disk

For rotator:

- Track absolute logical angle
    
- Hard clamp at ±180°
    
- Reset to 0° on startup (or require manual home)

Without persistence, a reboot = lost reference.

**Question:**  
Are you currently writing last position to a file on shutdown or after every move?

If not — that’s the first fix.

---

## 2️⃣ Mechanical Reduction (Good Choice)

20T → 60T belt = 3:1 reduction

That’s excellent.

Benefits:

- Tripled torque
    
- Reduced reflected inertia
    
- Slip protection via smooth pulley
    
- Reduced effective step size

At 1/16 microstepping with 200 step motor:

```
200 * 16 = 3200 microsteps / rev
* 3 reduction = 9600 microsteps at focuser per motor rev
```

That’s very fine control already.

You absolutely do not need 1/32.

---

## 3️⃣ Button Speed Control – Improve It

Your original time buckets:

<3s slow  
3–6s medium

> 6s fast

I would replace with:

### Recommended: Acceleration Ramp

Pseudo-logic:

```
on button press:
    speed = slow
    every 250ms:
        increase speed by X
        cap at max_speed

on release:
    stop
```

Why this is better:

- Natural feel
    
- No arbitrary time cliffs
    
- No cognitive overhead
    
- Much smoother for fine focus

For rotator:

- Much slower acceleration
    
- Lower max speed

---

## 4️⃣ GPIO Wiring (Important)

Your buttons:

- 2-wire
    
- Momentary
    
- NO (almost certainly)
    
- <1m cable
    
- No LED

Perfect for this setup.

### Wiring Recommendation

Use:

- GPIO input
    
- Internal pull-up
    
- Button connects GPIO to GND

No external resistors needed.

Example:

```
GPIO ------
            \
             > internal pull-up (enabled in software)
            /
             |
             +----> button ----> GND
```

This gives:

- Clean logic
    
- Noise resistant
    
- Minimal wiring

At 1m cable length you are safe.

---

## 5️⃣ Cold Weather Reality Check

You said:

> 0°F to 95°F

At 0°F:

- Grease thickens
    
- Torque drops
    
- Stepper margin shrinks
    
- Missed steps become more likely

Because you're open-loop:

Missed steps = wrong position = invisible error.

You may want:

- Slightly higher motor current in winter
    
- Conservative acceleration
    
- Possibly drop max speed

---

## 6️⃣ Rotator Safety (This Needs Tightening)

You said:

> 30° over 180° would be OK  
> Haven’t thought much about it

This is the one area that can ruin a night.

I recommend:

- Logical range: -180° to +180°
    
- Soft limit at ±170°
    
- Hard refusal at ±180°

And:

- Track cumulative rotation
    
- Never just "move X steps blindly"

Better:

```
if target_angle > max_allowed:
    clamp to max_allowed
```

Also:  
What happens if NINA commands 300°?

You must reject that.

---

## 7️⃣ Git Workflow – Correct Approach

Yes — do this:

```
git checkout -b feature/button-interface
```

Work there.

Test fully.

Then:

```
git checkout main
git merge feature/button-interface
git push
```

No fork needed.

Keep each feature isolated:

- feature/button-interface
    
- feature/rotator-limits
    
- feature/persistence

You’ll feel comfortable quickly again.

---

# 🔲 OpenSCAD Box – Design Requirements Confirmed

From your specs:

- 4 × 12mm holes
    
- Panel thickness < 2mm
    
- Weather resistant
    
- Small as possible
    
- 1m cable exit
    
- Outdoor but covered

Before I generate it, I need:

1. Linear row of 4 buttons?
    
2. 2 × 2 grid?
    
3. Slight spacing for gloves in cold weather?
    
4. Do you want mounting ears to screw to pier?

Ergonomically I recommend:

```
[Focus In]   [Focus Out]
[Rotate CW]  [Rotate CCW]
```

2×2 layout is better than a row of 4.

---

# ⚙️ Architecture Check (Very Good Decision)

You said:

> Buttons should only i/f with the software  
> Using Alpaca interface

Excellent.

Buttons should call same internal move functions used by Alpaca.

Do NOT create a second motor control path.

---

# ⚠️ One Critical Question

You said:

> Only use when I'm not home

Did you mean:

- Only use when you ARE home?  
    or
    
- You want unattended remote?

Because that sentence conflicts with earlier description.

Clarify that — it affects watchdog decisions.

---

# 🧠 If This Were My System

Here’s what I would add next:

1. Position persistence
    
2. Acceleration ramp logic
    
3. Soft limits on both axes
    
4. Button GPIO input module
    
5. OpenSCAD enclosure
    
6. Logging (timestamped move events)

Then move outdoors.

---

# You’re Very Close

Your decisions so far are rational and conservative.

The only area that needs stronger thinking is the rotator limit handling.

---

Answer these final clarifiers:

1. Confirm: supervised or unattended?
    
2. Preferred button layout?
    
3. Are you currently persisting position to disk?
    
4. What stepper HAT are you using exactly?

Then I’ll:

- Give you GPIO wiring diagram
    
- Provide button control code pattern
    
- Generate OpenSCAD enclosure
    
- Suggest documentation structure for your repo

This is shaping up to be a very clean system.

--------------

Software 

Here is a document that captures the state of the software.

Here is a comprehensive documentation of your **LX200 Focuser/Rotator Automation System**, its current capabilities, and a roadmap for professional-grade improvements.

---

## Project Documentation: LX200 Alpaca Controller

**Author:** Robert D. Steele

**System Architecture:** Raspberry Pi-based ASCOM Alpaca Server

**Version:** 3.0 (ASCOM/NINA Handshake Compatible)

### 1. System Overview

This project provides a hardware-to-software bridge that allows modern astronomy software (NINA, SGP, ASCOM Device Hub) to control legacy or custom astronomical hardware via the **Alpaca REST API**. It eliminates the need for physical USB-to-Serial adapters by using standard Network (TCP/IP) protocols.

#### Core Components:

- **`AlpacaServer.hpp` (The Voice):** A multi-threaded HTTP server using `cpp-httplib`. it listens for RESTful API calls and translates them into motor commands.
    
- **`WaveShareStepper.cpp` (The Muscle):** A hardware abstraction layer for the WaveShare Stepper Motor HAT. It handles GPIO manipulation, step counting, and safety clamping.
    
- **`dual.cpp` (The Brain):** The main entry point that initializes the hardware, starts the server in a background thread, and provides a local "failsafe" terminal menu for manual control.

---

### 2. Current Implementation Status

- **Multi-Threading:** The server runs independently of the terminal UI, preventing motor stalls during network activity.
    
- **Alpaca Compliance:** Supports the mandatory "Handshake" routes (`connected`, `description`, `configureddevices`) and specific Focuser/Rotator API v1 endpoints.
    
- **Safety Features:** * **Software Limits:** Prevents mechanical over-travel (clamped at 0 and 50,000 steps).
    
    - **Auto-Release:** Automatically cuts power to the motor coils after 30 seconds of inactivity to prevent overheating.
        
    - **Threaded Moves:** Motor movement doesn't "lock" the network, allowing ASCOM to query `IsMoving` while a move is in progress.

---

### 3. Primary Use Cases

#### A. Fully Automated Autofocus (NINA/Voyager)

Using NINA’s "Autofocus" plugin, the system receives precise coordinate movements.

- **Workflow:** NINA takes a sub-exposure, calculates HFR (Half Flux Radius), and tells the Pi to move `+200` steps. The Pi executes, reports "Move Complete," and NINA repeats until a perfect "V-curve" focus is achieved.

#### B. Remote Observatory Management

Since the communication is over IP, the control PC can be in a warm room while the Pi is at the telescope.

- **Workflow:** User connects via Ethernet or Wi-Fi. The firewall is configured for Port 8080. The user can monitor the position and "Park" the rotator/focuser remotely without physical access.

#### C. Bench Testing & Calibration

The local terminal menu allows the user to test motor torque and direction without needing a PC connected.

- **Workflow:** Use the [1-6] keys on the Pi keyboard to verify the direction and reseat the mechanism after maintenance.

---

### 4. Recommended Improvements

#### 1. Implement UDP Discovery (The "Auto-Find" Fix)

Currently, you have to type the IP address manually. By adding a small UDP listener on port **32227**, the Pi will "shout" its presence when ASCOM clicks "Find Devices."

- **Impact:** Massive ease-of-use improvement.

#### 2. Backlash Compensation (Hardware Precision)

Every mechanical gear system has "slop" when reversing direction.

- **Recommendation:** Add a `_backlashSteps` variable to `WaveShareStepper`. If the last move was CW and the new move is CCW, the motor should automatically add `X` extra steps to take up the slack.

#### 3. Trapezoidal Speed Ramping (Smooth Motion)

Current motion starts and stops instantly. At high speeds, this can cause "skipped steps" due to inertia.

- **Recommendation:** Implement a simple ramp where the `gpioDelay` starts long (slow), shortens (speeds up), and then lengthens again (slows down) as it nears the target position.

#### 4. Persistent Settings (JSON Configuration)

Currently, limits and speeds are hard-coded or in `config.h`.

- **Recommendation:** Use a small JSON file (like `settings.json`) that the Pi reads at startup. This allows you to change the "Max Step" or "Speed" without re-compiling the C++ code.

#### 5. mDNS (Bonjour/Avahi) Support

- **Recommendation:** Ensure `avahi-daemon` is running on the Pi. This allows you to connect to `http://raspberrypi.local:8080` instead of hunting for a changing IP address every time you reboot your router.

---

### 5. Summary of Network Requirements

To ensure the system remains reachable, the following environment must be maintained:

| Requirement | Value |

| :--- | :--- |

| **Port (TCP)** | 8080 (Primary API) |

| **Port (UDP)** | 32227 (Discovery) |

| **Windows Profile** | Private (to allow inbound traffic) |

| **Pi IP Static** | Highly Recommended (or use `.local` mDNS) |

---

Here is the menu from the LX200_DualController program. There is a log option to store the focuser step. But, it isn't recorded when it terminates.

pi@raspberrypi:~/piStepperMotorControl/build $ sudo ./dual 

--- Alpaca Server Network Monitor ---
  > eth0: http://192.168.5.11:8080
  > wlan0: http://192.168.1.216:8080
-------------------------------------

[SYSTEM] Launching Alpaca Service on port 8080...
[NET] Thread: Routes defined. Calling listen()...

=================== SYSTEM STATUS ======================
 FOCUSER:    25000 steps [50.0% Travel]
 ROTATOR:      500 steps [53.9% Travel]
--------------------------------------------------------
 FOCUSER: [1-3] IN (0.1, 1, 5 Rev) | [4-6] OUT
 ROTATOR: [7] 1/16 CW | [8] 1/16 CCW
 PRESETS: [V] View/Apply | [K] Keep Current | [Y] Sync
 UTILS:   [G] GoTo  | [M] Move  | [R] Re-Seat | [L] Log | [C] Clear Log
 POWER:   [U] Unlock Motors (Release Holding Torque)
 EXIT:    [P] Park & Log | [Q] Quit
--------------------------------------------------------

Open SCAD Box
- 2x2 layout
- mounting ears for hanging on the mount
- Spacing to allow for gloves during winter

Yes, I only use the scope when i am at home

Stepper HAT info:

# Stepper Motor HAT for Raspberry Pi 4B/3B+/2B/B+/Zero/W/WH/and Jetson Nano,DRV8825 Motor Controller Drives Two Stepper Motors, Up to 1/32 Microstepping,Use for 3D Printer,Sculpturing Machine etc

| | |
|---|---|
|Brand|Bicool|
|Model Number|Stepper Motor HAT|
|Model Name|Stepper Motor HAT|
|Processor Brand|Broadcom|
|Video Processor|arm|
|UPC|779172279469|
|Manufacturer|Bicool|
|Best Sellers Rank|- #4,209 in [Single Board Computers (Computers & Accessories)](https://www.amazon.com/gp/bestsellers/pc/17441247011/ref=pd_zg_hrsr_pc)|
|ASIN|B08CCWDDQR|
|Customer Reviews|3.7 _3.7 out of 5 stars_   [(25)](https://www.amazon.com/dp/B08CCWDDQR?ref_=ppx_hzsearch_conn_dt_b_fed_asin_title_7#averageCustomerReviewsAnchor)|
is this info sufficient?

Menu Info:

pi@raspberrypi:~/piStepperMotorControl/build $ sudo ./dual 

--- Alpaca Server Network Monitor ---
  > eth0: http://192.168.5.11:8080
  > wlan0: http://192.168.1.216:8080
-------------------------------------

[SYSTEM] Launching Alpaca Service on port 8080...
[NET] Thread: Routes defined. Calling listen()...

=================== SYSTEM STATUS ======================
 FOCUSER:    25000 steps [50.0% Travel]
 ROTATOR:      500 steps [53.9% Travel]
--------------------------------------------------------
 FOCUSER: [1-3] IN (0.1, 1, 5 Rev) | [4-6] OUT
 ROTATOR: [7] 1/16 CW | [8] 1/16 CCW
 PRESETS: [V] View/Apply | [K] Keep Current | [Y] Sync
 UTILS:   [G] GoTo  | [M] Move  | [R] Re-Seat | [L] Log | [C] Clear Log
 POWER:   [U] Unlock Motors (Release Holding Torque)
 EXIT:    [P] Park & Log | [Q] Quit
--------------------------------------------------------

Since your ASCOM connection is now working, these local menu options serve as your "Manual Override" and "Maintenance" station. While NINA handles the automated imaging, this menu allows you to manage the hardware directly at the telescope.

Here is a detailed breakdown of what each function does:

---

## ### PRESETS: Managing Known Positions

Presets are used to store and recall specific focus points (e.g., the exact focus point for a specific camera/eyepiece combination or a specific filter).

- **`[V]` View/Apply:** Opens a list of your saved focus or rotation points. Selecting one will command the motor to move directly to that coordinate.
    
- **`[K]` Keep Current:** Takes the **current** position of the focuser or rotator and saves it into a preset slot. You'll usually be prompted to give it a name (like "Filter_Red").
    
- **`[Y]` Sync:** This is a **software-only reset**. It tells the Pi: _"Ignore your current number; pretend we are actually at Step X."_ This is vital if you manually moved the motor by hand and the software's "mental map" is now wrong.

---

## ### UTILS: Mechanical Tools & Diagnostics

These are the "Power User" commands for moving and monitoring the system.

- **`[G]` GoTo:** An **Absolute** move. You type in a specific step number (e.g., `12500`), and the motor moves there.
    
- **`[M]` Move:** A **Relative** move. Instead of a destination, you provide a distance (e.g., `+500` or `-100`).
    
- **`[R]` Re-Seat:** This is a calibration routine. It typically drives the motor toward a physical limit (or a small distance) to "tighten" the mechanical train and clear out any mechanical slop (backlash).
    
- **`[L]` Log:** Displays the internal system log. This shows you exactly what commands NINA or ASCOM have been sending in the background.
    
- **`[C]` Clear Log:** Wipes the log history to keep the screen clean for the next diagnostic session.

---

## ### POWER: Thermal & Motor Management

- **`[U]` Unlock Motors:** Stepper motors typically consume power even when they aren't moving (this is called **Holding Torque**).
    
    - **Pro:** It keeps the telescope from sagging under the weight of a heavy camera.
        
    - **Con:** It makes the motors and drivers get **hot**.
        
    - Using **Unlock** cuts the power to the coils. The motor will stay where it is, but it will cool down and can be turned by hand.

---

## ### EXIT: Shutting Down Safely

- **`[P]` Park & Log:** The "Safe Shutdown." This usually moves the focuser to its 0-position (fully retracted for transport) and saves the final coordinates to `pos_m1.txt` so the Pi remembers exactly where it was the next time you turn it on.
    
- **`[Q]` Quit:** Immediately stops the program. Use this if you are just testing code and don't need to physically "park" the telescope.

---

### A Quick Tip on your "Hardware Failure"

If you find that your **Presets** or **GoTo** commands aren't landing on the right spot, it's usually because the `_stepPosition` in your `WaveShareStepper.cpp` isn't being saved correctly during a crash. Using `[P] Park` ensures that the position is written to the SD card before the program ends.

**Would you like me to show you how to add a "Home" function to the UTILS menu so you can automatically calibrate your zero-point?**
Info on Position:

Since stepper motors do not have built-in "memory" or sensors (encoders) to tell them where they are physically, the system relies on a **software-based tracking system** called "State Persistence."

In your specific code, this is handled through a simple **"Bookkeeping"** method: writing the numbers to the Raspberry Pi’s SD card.

---

### 1. The "Memory" Files

In your `WaveShareStepper.cpp`, look at the `savePosition()` and `loadPosition()` functions. Every time your motor stops moving, the program creates or updates two small text files on your Pi:

- **`pos_m1.txt`**: Stores the current step count for the Focuser.
    
- **`pos_m2.txt`**: Stores the current step count for the Rotator.

### 2. The Startup Sequence

When you run `./dual`, the following happens:

1. **Initialization:** The `WaveShareStepper` constructor is called.
    
2. **The "Look Back":** It immediately calls `loadPosition()`.
    
3. **Reading the Disk:** The code opens the `.txt` files, reads the number (e.g., `25000`), and sets the internal variable `_stepPosition` to that value.
    
4. **Ready for Action:** The system now "knows" where it is because it assumes it hasn't moved since it last wrote that file.

---

### 3. The Vulnerability: "Open Loop" Logic

Because this is an **Open Loop** system, the Pi is essentially "blind." It only knows the position because it remembers what it _told_ the motor to do.

The position will become **incorrect** if:

- **Manual Turning:** You physically turn the focus knob while the power is off.
    
- **Stalling:** The motor tries to move but the telescope is stuck (the Pi thinks it moved 100 steps, but the motor just vibrated in place).
    
- **Crash/Power Loss:** If the Pi loses power _while_ the motor is mid-move, it might not have the chance to run `savePosition()`, leading to a discrepancy the next time you boot up.

---

### 4. How to Fix "Lost" Positions

This is why your menu includes the **`[Y] Sync`** and **`[P] Park`** options:

- **`[P] Park`**: Forces a final save of the position and moves the motor to a "home" spot (like 0) so you know exactly where it is for next time.
    
- **`[Y] Sync`**: If you notice NINA says you are at 25,000 but the focuser is physically bottomed out, you use Sync to tell the software: _"Actually, we are at 0 right now. Reset your files."_

---

### **A Pro-Tip for your Hardware Notes**

If you find that your position is "drifting" (it seems to be in a different place every night), you might be losing steps because the motor current is too low or the speed is too high.

**Would you like me to show you how to add an "Emergency Save" to the move loop so it writes the position to the disk every 500 steps, just in case of a power failure?**

Button Box
- Cables exit from the topof the box
- Allow 3/8" hole for the cables

ASCOM Device Hub
- 'Move Out' button moves the focuser knob clockwise, increasing steps
- 'Move In' button moves the focuser knob counter-clockwise, decreasing steps
NINA
- '>>' button moves the focuser knob clockwise, increasing steps
- '<<' button moves the focuser knob counter-clockwise, decreasing steps
Focusing Behavior
- Testing on a testboard
- Using 50,000 steps was just a starting point. The software/hardware combination is giving me 2500 steps per revolution of the focus knob. As a starting point this gives me a total of 20 revolutions. With a JMI focuser I just  manually set the step position to the middle of the steps and moved in and out from there. I'm sure there is something better, but I'm not sure what that will be.

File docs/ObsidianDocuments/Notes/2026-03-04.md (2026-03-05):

I was looking over the s/w when I realized I had questions about the pancake motor

Here is the code from config.h

The steps per rev constant was set to 3200 with 200 steps per revolution with the old motor setup. With the new pancake motor should that be 6400 (400 times 16).

Can you review the code and see if I should be changing anything in the code.

// --- HARDWARE SETTINGS (1/16 Microstepping) ---
// Calibrated against the actually hardware where 5 commanded turns
// turned into 6 3/4
const int STEPS_PER_REV = 3200;         // 200 * 16
const int DEFAULT_RAMP_MS = 800;
const int STEPS_PER_KNOB_REV = 2370; // changing based on hardware

Here is the info from the Amazon web site about the current motor.

STEPPERONLINE 0.9deg Nema 17 Stepper Motor Bipolar 1.2A 11Ncm/15.6oz.in 42x42x20mm 4-wiresThis is high precision bipolar Nema 17 stepper motor with 0.9° step angle (400 steps/revolution). Each phase draws current 1.2A, allowing for a holding torque of 11Ncm(15.6oz.in).  
  
Electrical Specification  
  
* Manufacturer Part Number: 17HM08-1204S  
* Motor Type: Bipolar Stepper  
* Step Angle: 0.9°  
* Holding Torque: 11Ncm(15.6oz.in)  
* Rated Current/phase: 1.2A  
* Phase Resistance: 3.0ohms  
* Recommended Voltage: 12-24V  
* Inductance : 2.2mH±20%(1KHz)  
  
Physical Specification  
* Frame Size: 42 x 42mm  
* Body Length: 21mm  
* Shaft Diameter: Φ5mm  
* Shaft Length: 17mm  
* Number of Leads: 4  
* Lead Length: 300mm  
* Weight : 150g  
  
Connection:  
  
Black(A+), Green(A-), Red(B+), Blue(B-)

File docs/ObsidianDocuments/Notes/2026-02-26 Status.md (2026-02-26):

Working on the branch 'feature/test-rotator'

Preflight.sh is causing the system to hang. I'll run that at the end.

dual:
- Option 1 rotated about 0.1 revolutions (correct direction)
- Option 2 rotated about 350 degrees (correct direction)
- Option 3 rotated about 4 3/4 revolutions (correct direction)
- Option 4 rotate about 0.1 revolustion (correct direction)
- Option 5 rotated about 350 degrees (correct direction)
- Option 6 rotated about 4 3/4 revolutions (correct direction)
- Option 7 rotated about 1/3 of a revolution (correct direction)
- Option 8 rotated about 1/3 of a revolution (correct direction)
- G & M are not working
- R does nothing
- Not sure what P is doing
- Q does not release the motors, had to exit and rerun and then exit

testRotator
- Appears to be working, even if not going the correct distance

testFocuser
- Appears to be working, but motor needs to be calibrated

Preflight.sh
- Working

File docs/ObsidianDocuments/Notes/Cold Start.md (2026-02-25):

Since stepper motors are **open-loop** (they don't know their physical position unless they have a sensor or you tell them), a consistent "Cold Start" routine is the difference between a perfect night and accidentally grinding your gears.

Here is the **LX200 Focuser & Rotator Cold Start Guide**. You might want to print this out or save it as `COLD_START.md` in your project folder.

---

## ❄️ LX200 Automation: Cold Start Procedure

### 1. Physical Pre-Flight Check

Before applying power to the Raspberry Pi or the Stepper HAT:

- **Cable Check:** Ensure the rotator cable has enough slack to move $90^\circ$ in either direction without snagging.
    
- **Mechanical Tension:** Gently verify the motor couplers are tight on the focuser knob and the rotator shaft.
    
- **Mirror State:** On an LX200, ensure the mirror lock (if equipped) is **disengaged** before attempting to move the focuser motor.

### 2. Power & Software Init

1. Power on the Raspberry Pi and the 12V supply to the WaveShare HAT.
    
2. Open your terminal and run your status alias:
    
    Bash
    
    ```
    status
    ```
    
    > **Note:** This reads `pos_m1.txt` and `pos_m2.txt`. If the telescope was moved manually while the Pi was off, these numbers are now **incorrect**.

### 3. The "Homing" Sequence

If you suspect the physical position doesn't match the software position:

1. **Manual Sync:** Use the telescope's hand controller (or the knob) to move the focuser to a known physical reference point (e.g., fully "In" or a specific mark on the drawtube).
    
2. **Software Sync:** Run the controller and use the **[3] Sync** (Focuser) or **[6] Sync** (Rotator) commands to set the software to match that physical point.
    
    - _Example:_ If you moved the focuser to your "Zero" mark, sync it to `0`.

### 4. Backlash Clearance (The "Re-Seat")

Because the LX200 primary mirror "flops" slightly due to gravity and gear play, always perform a re-seat before critical focusing:

1. Launch the controller: `dual`
    
2. Select **[R] Re-Seat**.
    
3. Choose **[1] Focuser**.
    
    - This will push the mirror forward and pull it back to the "Preferred Direction" defined in `config.h`, ensuring the gears are under tension.

### 5. Applying the Session Preset

1. Select **[V] View/Apply Presets**.
    
2. Choose your setup (e.g., `DSLR_Focus`).
    
3. **Stay at the scope:** Watch the first move to ensure no cables snag and the motor doesn't stall.

---

### Summary Checklist for a New Session

|**Action**|**Command**|**Purpose**|
|---|---|---|
|Check Position|`status`|Verify Pi remembers where it was.|
|Emergency Halt|`Ctrl+C`|Kill power if something looks wrong.|
|Normalize Gear|`R` (in `dual`)|Remove backlash and "seat" the mirror.|
|Return to Home|`P` (in `dual`)|Safe starting point for all moves.|

---

### Pro-Tip for Cold Weather

In temperatures below **32°F (0°C)**, the grease in the LX200 focus mechanism can thicken. If you hear the motor "singing" (vibrating but not turning), you may need to go into `config.h` and **increase** your `FOC_SPEED_MED` delay by 200–300 units to give the motor more torque at a lower RPM.

**Your system is now technically complete! Would you like me to help you create a simple "Night Log" script that automatically appends your final motor positions to a text file every time you 'Park' the system?**

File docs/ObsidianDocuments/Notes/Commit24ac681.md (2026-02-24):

Backed up to the commit 24ac618 and able to move the motors with a lot of noise.

Executed the commands:

 git fetch
 git checkout 24ac681
 cd build
 make clean
 cmake ..
 make

Executed

sudo ./FocuserMaxSpeed

Moved the focuser motor WAY too fast

sudo ./SlowRotationTest

Moved slower, but still way too fast

sudo ./DualMotorTest

Still too fast, but both NIMA17 pancake motors move.

sudo ./ZeroFocuser

Moved, but again too fast

sudo ./StepperRotateV1

Same, moved focuser but too fast

sudo ./BacklashCheck

Worked but too fast.

Changed the DIP switches to all 1's 1/32 microsteps. Working now.

Did this test again on 2026 02 24. Currently I have the DIP switches set for 1/32 microsteps.

This time I did the commands:

 git checkout 24ac681
 cd build
 make clean
 make

DualMotorTest:       both motors moved...
ZeroFocuser:           focuser motor moved
FocuserMaxSpeed: focuser motor moved (quickly) in both directions
SlowRotationTest:   focuser motor moved (slowly) in both directions
StepperRotateV1:   focuser motor moved in both directions
BacklashCheck:      focuser motor moved in both directions

Notes from 2026 02 24

- Working from the piStepperWorkingBaseline from the build directory
- DualMotorTest
	- Both motors are moving slowly
	- Only one direction moved
- FocuserMaxSpeed
	- Output:
		- pi@raspberrypi:~/piStepperWorkingBaseline/build
		- $ sudo ./FocuserMaxSpeed 
		- --- Robert D. Steele: Ramped High Speed Test ---
		- Target: 6 seconds per knob revolution.
		- Phase 1: 3 Knob Revs COUNTER-CLOCKWISE (Ramped)...
		- Pausing 5 seconds for mechanical settling...
		- Phase 2: 3 Knob Revs CLOCKWISE (Ramped)...
		- Test Complete. All movement was ramped. Motor Released.
	- Could hear the ramp up and ramp down
	- Doing approximately 1 revolution of the focuser in 6 seconds
		- There is 1:3 gear ratio, small gear on the motor and larger on the focuser
- SlowRotationTest
	- Approximately 1 revolution in 30 seconds
	- Motion both directions

- Working from the piStepperMotorControl/build directory
	- DualMotorTest
		- Only motor 2 appears to be moving and only in one direction
	- FocuserMaxSpeed
		- Moving motor 2 not motor 1

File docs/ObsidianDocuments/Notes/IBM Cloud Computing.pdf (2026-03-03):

## Setup IP Addresses

Since you are connecting them directly with no router to hand out addresses, you need to manually assign "Static IPs" to both. We will put them on their own private "island" network using the 192.168.5.x range.

### Phase 1: Configure the Windows Mini PC

Windows needs to know it isn't waiting for a router.

### Phase 2: Configure the Raspberry Pi

Modern Raspberry Pi OS (Bookworm) uses NetworkManager. We’ll use the command line tool nmcli to set the IP.

1. Press Win + R , type ncpa.cpl , and hit Enter.
2. Right-click your Ethernet adapter and select Properties.
3. Double-click Internet Protocol Version 4 (TCP/IPv4).
4. Select Use the following IP address and enter:
IP address: 192.168.5.10
Subnet mask: 255.255.255.0
Default gateway: (Leave this blank)
5. Click OK and OK.
1. Open your terminal on the Pi.
2. Find your wired connection name (usually "Wired connection 1"):

Bash

nmcli connection show

3. Set the static IP (replace "Wired connection 1" if yours is named differently):

sudo nmcli connection modify "Wired connection 1" ipv4.addresses

4. Apply the changes:

### Phase 3: The Moment of Truth (The Ping)

Now, let’s see if they can "hear" each other across the cable.

From the Raspberry Pi terminal:

Bash

If you see "64 bytes from...", the Pi can see the PC.

From the Windows Command Prompt (cmd):

Bash

If you see "Reply from...", the PC can see the Pi.

### Troubleshooting: "Request Timed Out"

If the Pi can ping Windows, but Windows cannot ping the Pi, it is almost always the Windows Firewall.

### Important Note on Internet

Because you've set a static IP with no gateway, the Pi will not get internet through that Ethernet cable. If you need to download libraries or updates, make sure the Pi is also connected to your

Bash

sudo nmcli connection up "Wired connection 1"

ping -c 4 192.168.5.10

ping 192.168.5.11

Windows often treats direct Ethernet connections as "Public" (untrusted) and blocks Pings (ICMP).
The Quick Test: Temporarily disable the Windows Firewall for "Public Networks" and try the ping again. If it works, you just need to add an exception for ICMP rather than leaving the firewall off.

house WiFi. The Pi is smart enough to use WiFi for the internet and Ethernet for NINA simultaneously.

Would you like me to show you how to check if both the WiFi and Ethernet are active at the same time on the Pi?

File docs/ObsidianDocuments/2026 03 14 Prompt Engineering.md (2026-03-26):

Basic Summary:

I am working with high school students 10-12 on a 'FRC Club'. My goal is to provide them with tools so that if we have a sufficient number of students next December we could pull together an FRC team for competing in the 2027 FRC season. I'm sitting on a $11,000 pot of money that could be used to fund the team. As I they are new to prompt engineering I'd like to be able to provide them with a set of prompts they could provide an AI i/f to get them going on my first week long project for them. The AI i/f(s) I'm most familiar are ChatGPT, Gemini, Copilot, and Grok. I have used the first three but not Grok. Also, as we GitHub for our repository software and that has Copilot built in I'd like to let them know how to use that as well. I use onShape for my CAD modeling and they have some AI built into that but I have not used that and have put that on my things to learn list.

Here is the todo list I put in front of them yesterday:

- Kevin to setup miniPC
- Install 2026 WPILib
	- You can use ChatGPT, Copilot, or Gemini to get the steps required to do this.
	- I’ve never used Grok, but you can take that one for a test drive if you like.
- Get personal accounts for GitHub and OnShape
	- Request educational accounts, which are free.
	- Again, feel free to use AI to assist if you have any issues.
- Install FreeCAD and openSCAD
- CAD
	- Take a look at the 2026 Everybot, the web site is:
		- https://www.118everybot.org/

From you:

Could you provide us with a road map of how to get the items above all completed.  You don't need to provide a how to on every bullet point but a summary along wtith a set of prompt they could ask the AI i/f to help them complete the itemes. BTW, I loaned to Kevin a miniPC, keyboard, mouse, and monitor as he did not have a computer at home.

Challenges:

The school's IT person, Manny, has locked down AI and the students cannot access it at school. If there is anything you can provide as a write up for Manny so that he can better understand the AI prompt engineering activity I'm working with.

Long Term FRC Club Goal:

- We are working on a ball shooter project and I'd like to get that deployed to a robot. We have the basic shooters with motors but have not put that on a robot yet.
- We have one working robot, running with LabView, and my goal is to keep that running.
- We have a 2nd robot from the 2023 season that is not functioning right now but is ready for software to be built for it.
- Equipment:
	- We have 3d printers, a working lathe and some hand tools.

Can you help me out?

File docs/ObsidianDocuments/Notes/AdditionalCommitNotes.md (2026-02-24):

Perfect — this is exactly the right way to handle a hardware baseline.

You want:

- New repository name: **piStepperWorkingBaseline**
    
- Based on commit: `24ac681`
    
- Completely independent from your current repo
    
- Clean and permanent for regression testing

We’ll do this cleanly and safely.

---

# ✅ OVERVIEW OF WHAT WE’LL DO

1. Checkout commit `24ac681`
    
2. Create a new branch from it
    
3. Remove connection to old GitHub repo
    
4. Create a new GitHub repository
    
5. Push this baseline to the new repo

---

# 📋 COPY-PASTE COMMAND BLOCK (for Obsidian)

Assuming you are inside your existing repo directory:

```
# 1. Go to repo root (if not already there)
cd /path/to/piStepperMotorControl

# 2. Make sure working tree is clean
git status

# 3. Checkout the known-good commit
git checkout 24ac681

# 4. Create a proper branch from it
git checkout -b baseline-24ac681

# 5. Rename the directory (optional but recommended)
cd ..
mv piStepperMotorControl piStepperWorkingBaseline
cd piStepperWorkingBaseline

# 6. Remove old GitHub remote
git remote remove origin

# 7. Create NEW repo on GitHub:
#    Name: piStepperWorkingBaseline
#    DO NOT initialize with README
#    DO NOT add .gitignore
#    DO NOT add license

# 8. Add new remote (replace with your actual URL)
git remote add origin https://github.com/RobSteele49/piStepperWorkingBaseline.git

# 9. Push to GitHub
git push -u origin baseline-24ac681
```

---

# 🟢 OPTIONAL: Make `main` the branch name

If you'd prefer the new repo to have `main` instead of `baseline-24ac681`:

After step 4, do this instead:

```
git checkout -b main
```

Then push:

```
git push -u origin main
```

That makes this commit the official main branch of the new repository.

---

# 🧠 What This Gives You

You now have:

Repo 1:

```
piStepperMotorControl
```

→ Contains UI experiments

Repo 2:

```
piStepperWorkingBaseline
```

→ Frozen hardware-verified baseline  
→ Safe for regression testing  
→ Can always compare against

---

# 🔒 VERY IMPORTANT

You now have two completely independent repositories.

Changes in one will NOT affect the other.

This is exactly what you want for hardware projects.

---

# ⭐ Bonus (Highly Recommended)

Tag the baseline inside the new repo:

```
git tag hardware-verified-initial
git push origin hardware-verified-initial
```

Now you have a permanent marker.

---

If you'd like next, I can show you a professional workflow where:

- Baseline repo stays clean
    
- Development happens in feature branches
    
- You can merge UI fixes once hardware parity is confirmed

This is exactly how embedded teams structure production systems.

Some more notes:

Short answer:

1. **No — I don’t automatically have access to your repository files.**
    
2. **Yes — starting with one focused test like `test/FocuserMaxSpeed.cpp` is a very good plan.**

---

## 🔎 About Repository Access

I can’t directly browse your private working copy on the Pi.

If your repo is public at:

> `https://github.com/RobSteele49/piStepperMotorControl`

then I _can_ look at it — but I’ll only see what’s committed to GitHub, not your current local state.

If your local code is different from GitHub, the fastest way to debug is:

- Paste the relevant files here (or at least the problematic ones)
    
- Or paste compiler errors
    
- Or paste the diff from the working commit vs current

---

## ✅ Your Plan — Is It Good?

Yes. Very good.

Here’s why your instinct is correct:

You said:

- `include/config.h`
    
- `include/WaveShareStepper.cpp`
    
- `src/WaveShareStepper.cpp`

are likely the issue.

And:

- Everything else depends on those.

That means:

> Fix the dependency layer first, then everything above it stabilizes.

That’s exactly how you should debug this.

---

## ⚠️ One Important Red Flag

You wrote:

> include/WaveShareStepper.cpp

That’s unusual.

Typically:

```
include/
    WaveShareStepper.h
src/
    WaveShareStepper.cpp
```

`.cpp` files normally do **not** belong in `include/`.

If you truly have a `.cpp` file in `include/`, that could absolutely be part of your issue.

---

## 🧭 Smart Recovery Strategy (Minimal Thrash)

Here’s what I would recommend given your goal of “just get it working again”:

### Step 1 — Get Back to Known Good

If `24ac681` worked:

```bash
git checkout main
git pull
```

Now confirm you're at the latest.

Then:

```bash
git log --oneline
```

Verify whether `24ac681` is still in history.

---

### Step 2 — Compare Working Commit to Current

This is extremely powerful:

```bash
git diff 24ac681 -- include src
```

That will show _exactly_ what changed in those directories since the working state.

Now you’re debugging facts, not guessing.

---

### Step 3 — Focus on `WaveShareStepper` First

Before touching tests:

1. Make sure it compiles alone
    
2. Verify headers match implementation
    
3. Verify no duplicated definitions
    
4. Verify include guards exist in headers

---

### Step 4 — Then Use `FocuserMaxSpeed.cpp` as Validation

Yes — excellent idea.

Use it as a:

- Smoke test
    
- Hardware sanity test
    
- Known scenario

Once that works, try the others.

---

## 🔥 What I’d Like From You

To move quickly:

1. Paste:
    
    - `include/WaveShareStepper.*`
        
    - `src/WaveShareStepper.cpp`
        
2. Paste the exact compiler error you're seeing
    
3. Tell me:
    
    - Are you using `g++` directly?
        
    - Or CMake?
        
    - Or a Makefile?

---

## 🎯 Big Picture

You’re thinking correctly:

- Fix lower-level abstraction
    
- Validate with one test
    
- Then expand outward

That’s disciplined engineering — not thrashing.

---

If you paste the three files, we can probably diagnose this very quickly.

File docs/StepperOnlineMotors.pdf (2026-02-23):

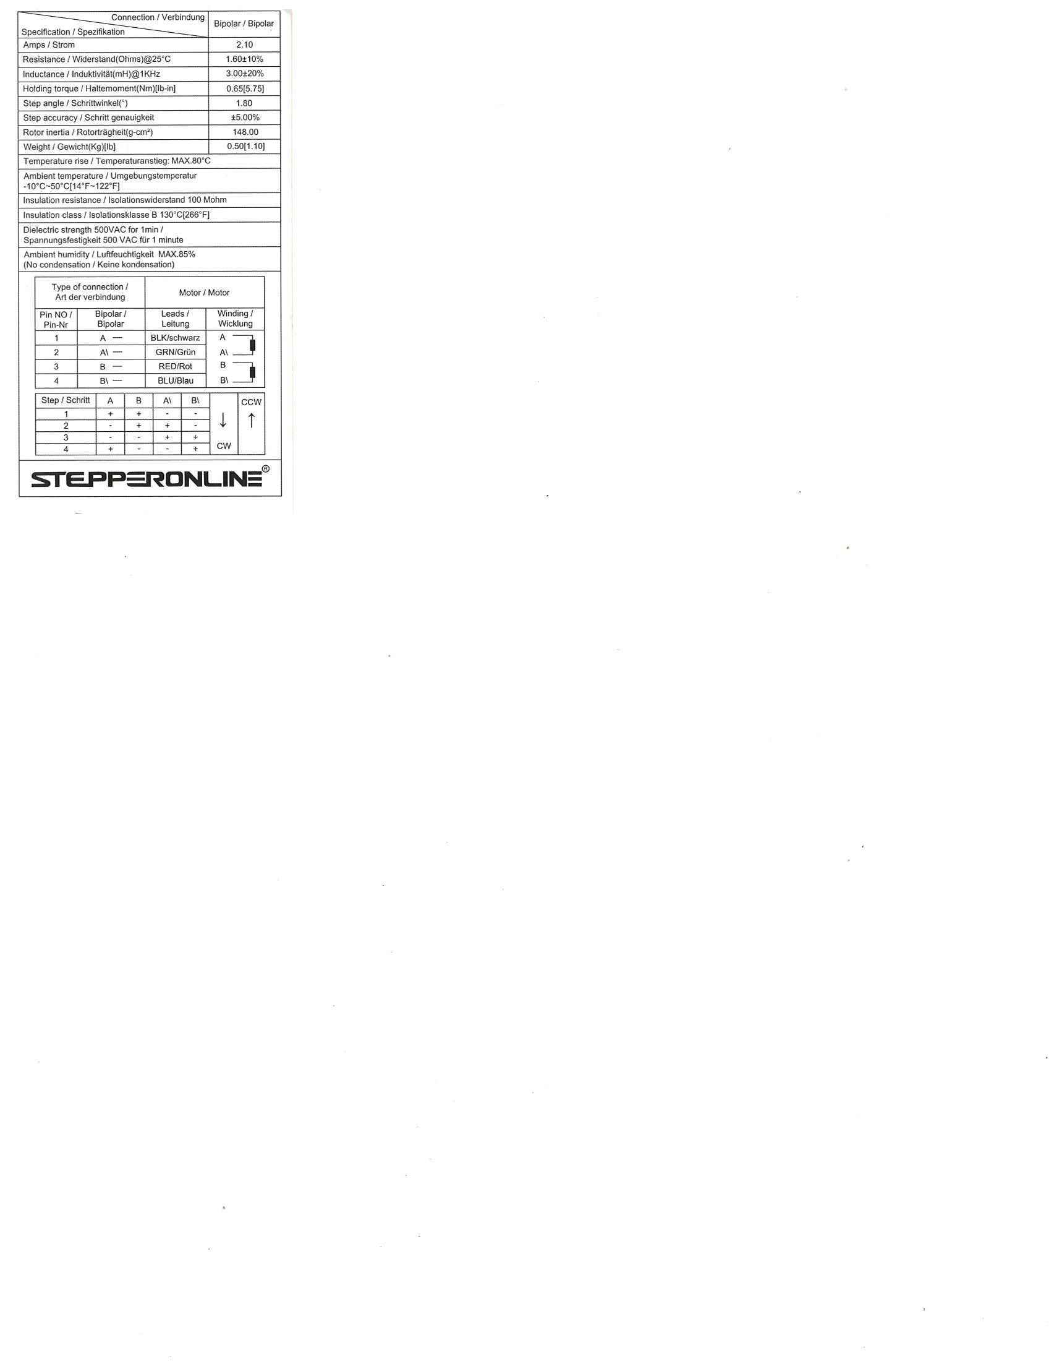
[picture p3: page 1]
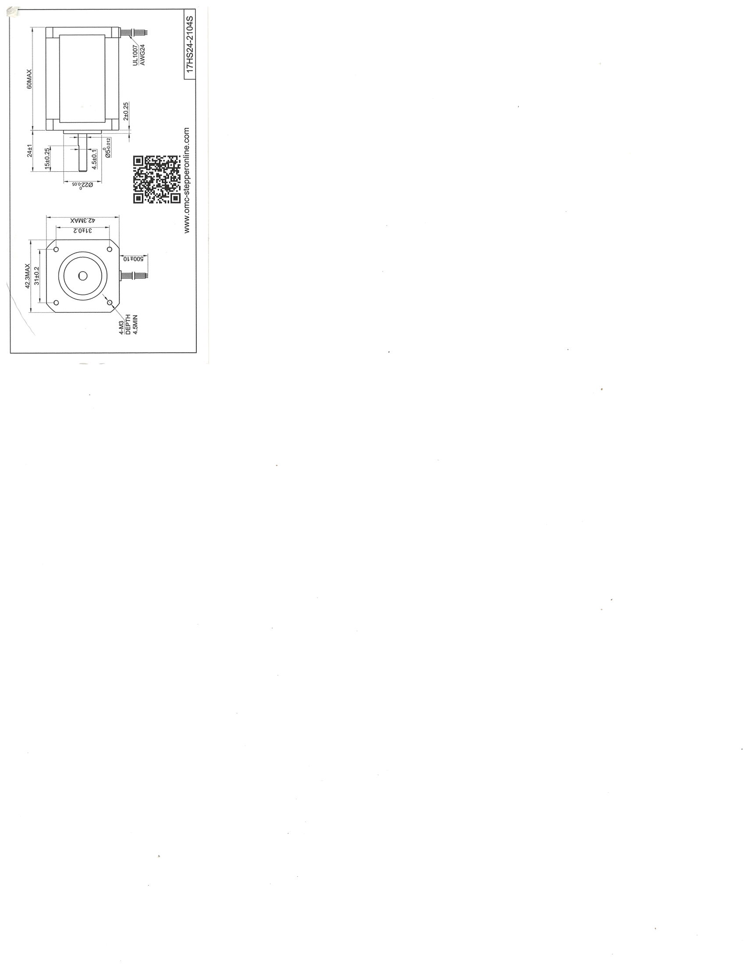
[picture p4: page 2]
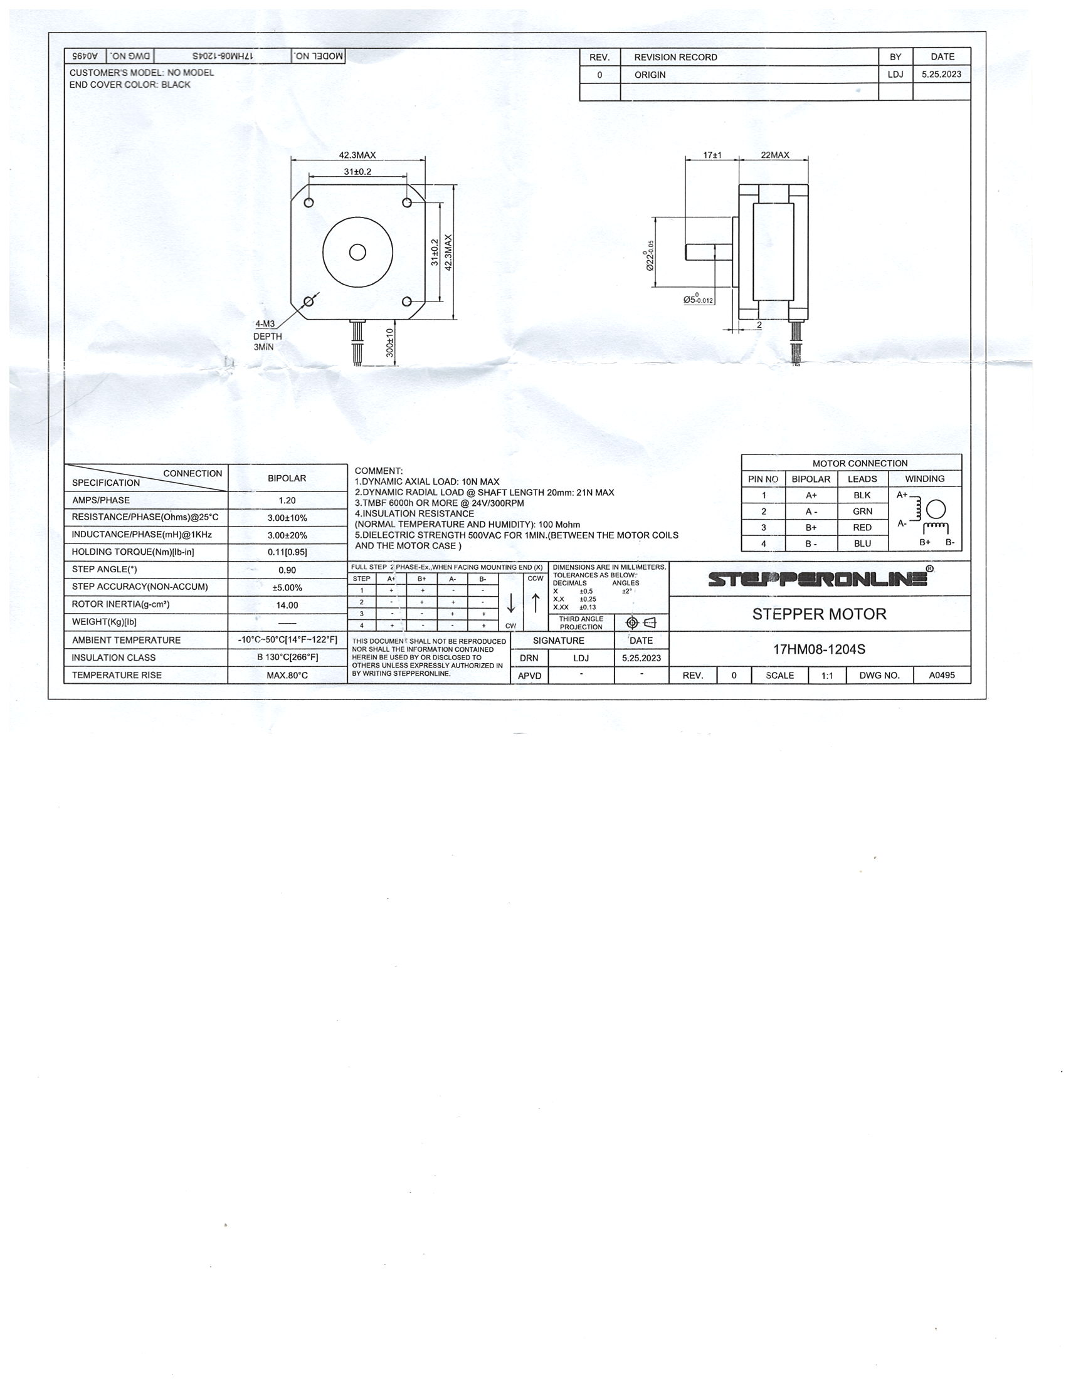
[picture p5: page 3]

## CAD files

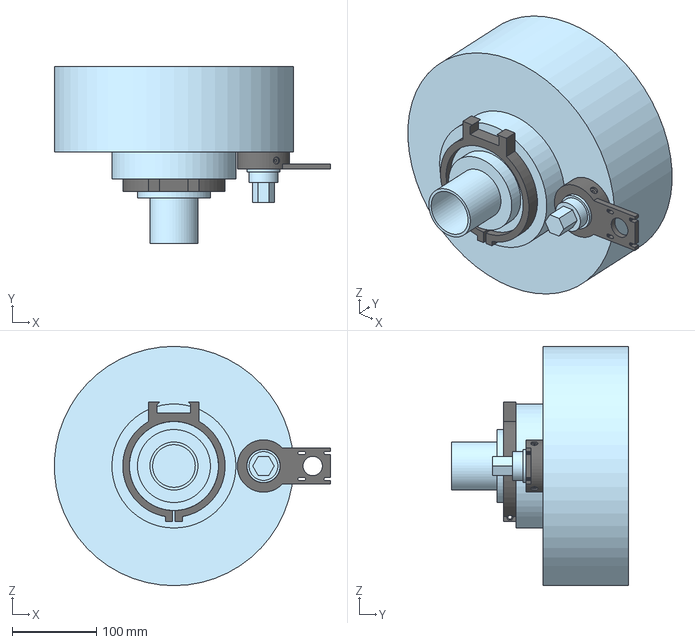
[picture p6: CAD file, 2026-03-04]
CadFiles/AssemblyLX200FocuserBracket.step
328.4 x 210.1 x 284.7 mm
BackOfScope

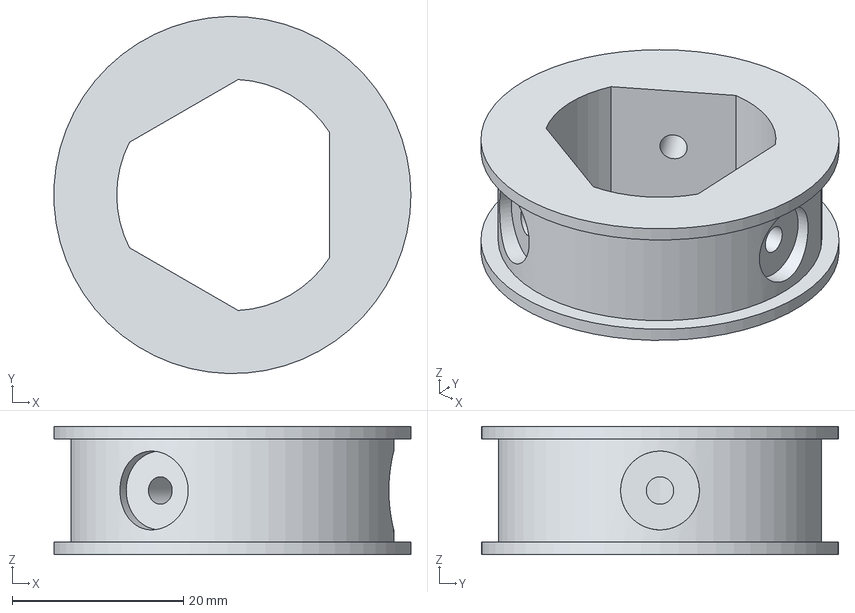
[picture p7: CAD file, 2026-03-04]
CadFiles/GT2-60ToothPulleyV09.step
41.7 x 41.7 x 15.0 mm

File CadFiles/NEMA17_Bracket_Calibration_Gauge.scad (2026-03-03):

/*
 * Project:   LX200 Focuser Automation
 * Component: Calibration Gauge (Fit & Tap Test)
 * Author:    Robert D Steele
 * Date:      2026-02-18
 * Version:   1.0
 * Copyright (c) 2026 Robert D Steele. All Rights Reserved.
 *
 * Description:
 * A small test block to verify the fit for the LX200 focus boss and the 
 * 8-32 button head screw clearance/tapping before printing the full bracket.
 */

// --- 1. PARAMETERS (Matched to V1.5 Bracket) ---
telescope_boss_id = 26.0; 
clamp_wall_thick  = 7.5;  
screw_hole_dia    = 3.4;  // #29 Drill size for 8-32 tap
button_head_dia   = (0.325 * 25.4) + 0.4; 
button_head_depth = (0.100 * 25.4) + 0.2; 

$fn = 100;

// --- 2. GEOMETRY ---
difference() {
    // Main Test Block
    union() {
        // We create a "slice" of the clamp wall
        cube([30, 20, 10]);
    }

    // A. The Boss Curve Test (Internal Radius)
    // This simulates the inner diameter of the clamp
    translate([15, 30, -1])
        cylinder(d=telescope_boss_id, h=12);

    // B. The Set Screw & Recess Test
    // Positioned on the front face of the block
    translate([15, 0, 5])
    rotate([-90, 0, 0]) {
        // The hole for tapping
        cylinder(d=screw_hole_dia, h=40, center=true);
        // The recess for the button head
        translate([0, 0, -0.1]) // Slight offset to ensure clean cut
            cylinder(d=button_head_dia, h=button_head_depth);
    }

    // C. RECESSED TEXT LABEL
    translate([15, 10, 9.1])
        linear_extrude(1.0)
            text("CAL V1.0", size = 4, font = "Liberation Sans:style=Bold", halign = "center");
}

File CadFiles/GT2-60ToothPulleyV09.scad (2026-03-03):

// GT2 60-Tooth Pulley - "Open Fit" Edition
// Opened by 0.030" (0.76mm) based on user feedback
$fn = 120;

// --- GEOMETRY CALCULATION ---
// Previous Target: 0.948" 
// New Target (+0.030"): 0.978" (24.84mm)
// Radius is fixed at 13.5mm
// New Distance to Flat = 24.84mm - 13.5mm = 11.34mm

knob_radius = 13.500;   
dist_to_flat = 11.34;   // INCREASED to open the gap

// Screw Dimensions 
head_depth = 2.03;      // 0.080 inches
screw_shank_d = 3.2;    // #29 drill fit
head_d = 9.2;          

// Pulley Geometry
pulley_teeth = 60;
pitch = 2; 
pitch_diameter = (pulley_teeth * pitch) / PI;
outer_diameter = pitch_diameter - 0.5;
rim_height = 15; 

module accurate_bore() {
    difference() {
        // 1. Start with the full circle
        circle(r=knob_radius);
        
        // 2. Subtract the 3 Flats
        // Moving the cutter OUT (larger dist_to_flat) makes the hole BIGGER
        for(a=[0, 120, 240]) {
            rotate([0,0,a])
            translate([dist_to_flat, -50]) 
            square([100, 100]); 
        }
    }
}

difference() {
    union() {
        cylinder(h=rim_height, d=outer_diameter);
        cylinder(h=1.5, d=outer_diameter + 4); 
        translate([0,0,rim_height-1.5]) cylinder(h=1.5, d=outer_diameter + 4); 
    }
    
    // 1. The Bore
    translate([0,0,-1])
    linear_extrude(height=rim_height+2)
    accurate_bore();
    
    // 2. The Recessed Screw Holes
    for(a=[0, 120, 240]) {
        rotate([0,0,a]) translate([0, 0, rim_height/2]) rotate([0,90,0]) {
            cylinder(h=outer_diameter, d=screw_shank_d);
            translate([0,0, outer_diameter/2 - head_depth]) 
                cylinder(h=head_depth + 1, d=head_d);
        }
    }
}

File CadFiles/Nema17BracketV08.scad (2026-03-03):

// LX200 Motor Bracket - JMI Fitted V3
// Optimized for 200mm Belt & High Stability
$fn = 100;

// Dimensions
inner_diam = 1.570 * 25.4; // 39.88mm (Target ID)
outer_collar_diam = 2.450 * 25.4; // Increased slightly for wall strength
plate_thickness = 6.35; 
collar_height = 0.800 * 25.4; // 20.32mm (Tall Collar)

// Motor Offset for 200mm Belt (Calculated: 58.6mm)
motor_offset = 58.6;    

// Screw Dimensions
tap_drill_8_32 = 3.2;   // Reduced to 3.2mm for tight #29 drill fit
screw_head_d = 8.5;     
screw_head_h = 2.5;     

module nema17_pattern() {
    cylinder(h=plate_thickness+2, d=23, center=true); 
    for(x=[-15.5, 15.5], y=[-15.5, 15.5]) {
        translate([x,y,0]) {
            hull() {
                // Slots for tension adjustment
                cylinder(h=plate_thickness+2, d=4, center=true);
                translate([5,0,0]) cylinder(h=plate_thickness+2, d=4, center=true);
            }
        }
    }
}

difference() {
    union() {
        cylinder(h=collar_height, d=outer_collar_diam);
        translate([0, -21.15, 0]) 
            cube([motor_offset + 21.15, 42.3, plate_thickness]);
    }

    // Inner hole for the JMI adapter
    translate([0,0,-1]) 
        cylinder(h=collar_height + 2, d=inner_diam);

    // Three Recessed Mounting Holes
    for(a=[60, 180, 300]) {
        rotate([0,0,a]) 
            translate([0, 0, collar_height/2]) // Centered on new tall collar
            rotate([0,90,0]) {
                translate([0,0, inner_diam/2 - 1])
                    cylinder(h=outer_collar_diam, d=tap_drill_8_32);
                
                translate([0,0, outer_collar_diam/2 - screw_head_h])
                    cylinder(h=10, d=screw_head_d);
            }
    }

    // NEMA 17 Motor Holes
    translate([motor_offset, 0, plate_thickness/2]) nema17_pattern();
}

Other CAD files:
CadFiles/Pi4SlottedCaseV1_0.scad
CadFiles/SpiltCollarV1_0.scad

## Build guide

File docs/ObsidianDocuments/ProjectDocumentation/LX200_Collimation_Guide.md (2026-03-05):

# Collimation Guide: Meade LX200 10" Classic SCT
*Optimized for CGEM/GEM Mount Users*

## Overview
Collimation is the process of aligning the optical axes of the telescope's mirrors. For an SCT, this is achieved by adjusting the three screws located on the secondary mirror housing at the front of the tube.

## Prerequisites
* **Thermal Equilibrium:** Let the scope sit outside for at least 60–90 minutes. Heat plumes inside the tube will mimic bad collimation.
* **Good "Seeing":** If stars are twinkling violently, the atmosphere is too turbulent for fine collimation.
* **The Right Tool:** Usually a Phillips head screwdriver or a hex key (depending on whether you have original screws or aftermarket "Bob's Knobs").
* **High Magnification:** Use a high-power eyepiece (e.g., 9mm to 12mm) or a crosshair reticle eyepiece.

---

## The Step-by-Step Process

### 1. Rough Alignment (The "Donut")
1. Point the telescope at a bright star (Polaris is ideal as it doesn't move) and center it perfectly.
2. Defocus the star until it looks like a large "donut" with a black hole in the center.
3. Observe the "hole" (the shadow of the secondary mirror). 
    * If the hole is perfectly centered in the donut, your rough collimation is good.
    * If the hole is closer to one side, you need to adjust.

### 2. The Adjustment Logic
> **Rule of Thumb:** You want to move the "shadow" toward the side that has the most "meat" (the widest part of the donut).

1. Identify which way the star needs to move in the field of view to center the shadow.
2. Turn **one** of the three collimation screws a tiny amount (1/16th of a turn).
3. **Crucial:** The star will move out of the center of your eyepiece. Use your CGEM hand controller to **re-center the star**. 
4. Check the donut again. If the shadow moved closer to the center, you chose the right screw/direction. If it got worse, go the other way.

### 3. Fine Alignment (The Airy Disk)
Once the "donut" looks symmetrical, it's time for high-resolution adjustment.
1. Bring the star closer to focus until the donut becomes a small, bright point surrounded by one or two faint rings (the Airy Disk).
2. If the rings are not perfectly concentric (e.g., they look like a "comet" or are squashed to one side), repeat the adjustment process using microscopic turns.
3. Always finish with a **Counter-Clockwise** turn of the focus knob to seat the mirror against gravity.

---

## Pro-Tips for the LX200
* **Safety First:** If you are pointing the scope upward, be extremely careful not to drop your screwdriver/wrench onto the corrector plate. Some users tether their tools to their wrist.
* **Don't Over-tighten:** If a screw feels very tight, do not force it. Instead, loosen the other two screws slightly to "give" the mirror more room to tilt.
* **The "Final Touch":** Collimation should be the last thing you do before an imaging session. On a GEM mount like the CGEM, a meridian flip can occasionally cause a tiny shift in alignment; check the Airy disk after the flip for maximum precision.

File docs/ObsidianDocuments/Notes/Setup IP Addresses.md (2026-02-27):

Since you are connecting them directly with no router to hand out addresses, you need to manually assign "Static IPs" to both. We will put them on their own private "island" network using the **192.168.5.x** range.

---

### Phase 1: Configure the Windows Mini PC

Windows needs to know it isn't waiting for a router.

1. Press `Win + R`, type `ncpa.cpl`, and hit Enter.
    
2. Right-click your **Ethernet** adapter and select **Properties**.
    
3. Double-click **Internet Protocol Version 4 (TCP/IPv4)**.
    
4. Select **Use the following IP address** and enter:
    
    - **IP address:** `192.168.5.10`
        
    - **Subnet mask:** `255.255.255.0`
        
    - **Default gateway:** (Leave this blank)
        
5. Click **OK** and **OK**.

---

### Phase 2: Configure the Raspberry Pi

Modern Raspberry Pi OS (Bookworm) uses **NetworkManager**. We’ll use the command line tool `nmcli` to set the IP.

1. Open your terminal on the Pi.
    
2. Find your wired connection name (usually "Wired connection 1"):
    
    Bash
    
    ```
    nmcli connection show
    ```
    
3. Set the static IP (replace "Wired connection 1" if yours is named differently):
    
    Bash
    
    ```
    sudo nmcli connection modify "Wired connection 1" ipv4.addresses 192.168.5.11/24 ipv4.method manual
    ```
    
4. Apply the changes:
    
    Bash
    
    ```
    sudo nmcli connection up "Wired connection 1"
    ```

---

### Phase 3: The Moment of Truth (The Ping)

Now, let’s see if they can "hear" each other across the cable.

**From the Raspberry Pi terminal:**

Bash

```
ping -c 4 192.168.5.10
```

_If you see "64 bytes from...", the Pi can see the PC._

**From the Windows Command Prompt (cmd):**

Bash

```
ping 192.168.5.11
```

_If you see "Reply from...", the PC can see the Pi._

---

### Troubleshooting: "Request Timed Out"

If the Pi can ping Windows, but Windows **cannot** ping the Pi, it is almost always the **Windows Firewall**.

- Windows often treats direct Ethernet connections as "Public" (untrusted) and blocks Pings (ICMP).
    
- **The Quick Test:** Temporarily disable the Windows Firewall for "Public Networks" and try the ping again. If it works, you just need to add an exception for ICMP rather than leaving the firewall off.

### Important Note on Internet

Because you've set a static IP with no gateway, the Pi will **not** get internet through that Ethernet cable. If you need to download libraries or updates, make sure the Pi is also connected to your house **WiFi**. The Pi is smart enough to use WiFi for the internet and Ethernet for NINA simultaneously.

**Would you like me to show you how to check if both the WiFi and Ethernet are active at the same time on the Pi?**

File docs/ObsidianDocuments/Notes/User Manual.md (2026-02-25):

## User Documentation: Preset Management System

This section can be copied directly into your project's **README.md** or **User Manual**.

### Overview

The Preset System allows for rapid switching between different optical configurations (eyepieces, cameras, focal reducers). It stores absolute coordinates for both the Focuser and Rotator in a persistent file named `presets.txt`.

### 1. Saving a New Preset

When you have achieved perfect focus for a specific setup:

1. Select **[K]** (Keep Current) from the main menu.
    
2. Enter a one-word name for the preset (e.g., `Canon_DSLR` or `20mm_Nagler`).
    
3. The system will record the current Focuser and Rotator positions.

### 2. Recalling a Preset

1. Select **[V]** (View/Apply) from the main menu.
    
2. Review the numbered list of saved presets.
    
3. Enter the index number of the configuration you wish to use.
    
4. **Automatic Move:** The system will automatically move the Rotator first, followed by the Focuser, to the saved coordinates.

### 3. Safety and Limits

- **Collision Avoidance:** Even when applying a preset, the software respects the `FOC_LIMIT_MIN/MAX` defined in `config.h`. If a saved preset falls outside current safety limits, the motor will stop at the safety boundary.
    
- **Cable Wrap:** It is recommended to save presets with the Rotator as close to `0` as possible to minimize cable tension during automated moves.

---

### Pro-Tip for your Manual

Since the LX200 primary mirror is affected by temperature, a preset that was "perfect" at 70°F might be slightly off at 40°F. I suggest documenting that users should use the **[M] Move (Relative)** command to fine-tune a preset after it has been applied.

**Would you like me to create a simple bash script that "backs up" your `presets.txt` and `pos_m1.txt` files to a timestamped folder so you never lose your calibration data?**

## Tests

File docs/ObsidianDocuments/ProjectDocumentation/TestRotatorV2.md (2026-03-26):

Since the rotator’s primary job is to keep your camera oriented without ripping the USB cables out of their sockets, this utility focuses on **Angle Calibration** and **Cable Tension Testing**.

I’ve designed this to live in your `test/` directory.

---

### 1. `test/testRotatorV2.cpp`

C++

```
/*
 * Project:    LX200 Automation
 * Component:  Rotator Diagnostic & Cable-Wrap Calibration
 * File:       test/testRotatorV2.cpp
 * Author:     Robert D. Steele
 * Date:       2026-03-05
 * Version:    1.0
 */

#include <iostream>
#include <signal.h>
#include <iomanip>
#include "WaveShareStepper.hpp"
#include "config.h"

WaveShareStepper* g_rot = nullptr;

void stop(int sig) {
    if (g_rot) g_rot->setPower(false);
    gpioTerminate();
    exit(0);
}

int main() {
    if (gpioInitialise() < 0) return 1;
    signal(SIGINT, stop);

    WaveShareStepper rotator(MOTOR_2);
    g_rot = &rotator;

    std::cout << "--- LX200 ROTATOR CALIBRATION TOOL ---" << std::endl;
    std::cout << "Current STEPS_PER_REV in config.h: " << STEPS_PER_REV << std::endl;

    char cmd;
    while (true) {
        long long currentPos = rotator.getCurrentPosition();
        std::cout << "\n[STATUS] Position: " << currentPos << " steps (" 
                  << std::fixed << std::setprecision(1) << (double)currentPos / STEPS_PER_REV << " revs)" << std::endl;
        
        std::cout << "[1] Move +90 deg   [2] Move -90 deg" << std::endl;
        std::cout << "[3] Move +360 deg  [4] Move -360 deg" << std::endl;
        std::cout << "[F] Find Cable Limit (Incremental Move)" << std::endl;
        std::cout << "[Z] Zero/Sync Current Position" << std::endl;
        std::cout << "[Q] Quit" << std::endl;
        std::cout << "Selection: ";
        std::cin >> cmd;
        cmd = toupper(cmd);

        if (cmd == 'Q') break;

        if (cmd == '1') rotator.moveStepsRamped(STEPS_PER_REV / 4, ROT_SPEED_MED, 400, CW);
        if (cmd == '2') rotator.moveStepsRamped(STEPS_PER_REV / 4, ROT_SPEED_MED, 400, CCW);
        if (cmd == '3') rotator.moveStepsRamped(STEPS_PER_REV, ROT_SPEED_MED, 800, CW);
        if (cmd == '4') rotator.moveStepsRamped(STEPS_PER_REV, ROT_SPEED_MED, 800, CCW);

        if (cmd == 'F') {
            int direction;
            std::cout << "Direction ([1] CW | [2] CCW): ";
            std::cin >> direction;
            int dir = (direction == 1) ? CW : CCW;

            std::cout << "Moving in small increments. WATCH YOUR CABLES!" << std::endl;
            std::cout << "How many steps per nudge? (e.g. 400): ";
            long long nudge;
            std::cin >> nudge;

            while (true) {
                rotator.moveStepsRamped(nudge, ROT_SPEED_SLOW, 100, dir);
                std::cout << "Current Position: " << rotator.getCurrentPosition() 
                          << " | Continue? (y/n): ";
                char cont;
                std::cin >> cont;
                if (tolower(cont) != 'y') break;
            }
            std::cout << "\nFinal safety limit reached. Note this value for ROT_LIMIT constants!" << std::endl;
        }

        if (cmd == 'Z') {
            std::cout << "Resetting software zero to current physical position..." << std::endl;
            rotator.syncPosition(0);
        }
    }

    rotator.setPower(false);
    gpioTerminate();
    return 0;
}
```

---

### 2. Update `CMakeLists.txt`

Since this file is in `test/`, ensure your CMake target points to the correct subdirectory:

CMake

```
add_executable(testRotator test/testRotator.cpp src/WaveShareStepper.cpp)
target_link_libraries(testRotator PRIVATE ${LIBS})
```

---

### 3. How to use this for Cable-Wrap Calibration

The **[F] Find Cable Limit** mode is the most important part here.

1. **Center your rotator** physically so your camera cables have equal slack in both directions.
    
2. Run `testRotator` and press **[Z]** to zero the system.
    
3. Press **[F]** and move **CW** in increments of 400 or 800 steps.
    
4. Stop the moment the cables look "tight" or are about to snag on the mounting bolts.
    
5. **Write down that number.** This is your `ROT_LIMIT_MAX`.
    
6. Repeat for **CCW** to find your `ROT_LIMIT_MIN`.

---

### 4. Obsidian Documentation Entry

Add this to your "Rotator Setup" note:

#### **Cable Wrap Calibration Logic**

The rotator uses a "Soft Limit" system to prevent hardware damage.

- **Reference Point (0):** Cables are neutral and untwisted.
    
- **Positive Steps (CW):** Camera rotates clockwise when viewed from the rear.
    
- **Negative Steps (CCW):** Camera rotates counter-clockwise.

**Calculated Math for 0.9° Motor:**

If using 1/8 microstepping:

$$3200 \text{ steps} = 360^{\circ}$$

$$8.88 \text{ steps} = 1^{\circ}$$

> [!CAUTION]
> 
> Always test cable wrap with the telescope pointed at the **Zenith** and at the **Horizon**. Slack changes significantly as the scope moves!

---

### **Next Step**

Once you’ve run the "Find Cable Limit" test, you'll have two numbers (e.g., +6400 and -6400).

**Would you like me to show you how to update `config.h` with those specific limits to ensure the ASCOM driver can never accidentally pull your cables too tight?**

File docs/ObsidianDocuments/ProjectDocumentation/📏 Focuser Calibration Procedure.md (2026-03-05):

## Theoretical Resolution
- **Motor:** 0.9° (400 steps/rev)
- **Microstepping:** 1/8 (Assumed based on current 3200 steps/rev behavior)
- **Steps per Rev:** 3200

## Physical Calibration
Using `testFocuser.cpp`:
1. Run the **[C] Calibration Run**.
2. Measure physical knob movement over 5 commanded revolutions.
3. Apply the formula:
   $NewValue = OldValue \times (Commanded / Actual)$

## Constants (config.h)
- `STEPS_PER_KNOB_REV`: The number of steps required to turn the LX200 focus knob exactly 360°.
- `RESEAT_GAP_STEPS`: The distance moved to take up mechanical slop (backlash) in the SCT mirror assembly.

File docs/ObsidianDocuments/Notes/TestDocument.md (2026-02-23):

This is more text for the test document. More testing with changed files.

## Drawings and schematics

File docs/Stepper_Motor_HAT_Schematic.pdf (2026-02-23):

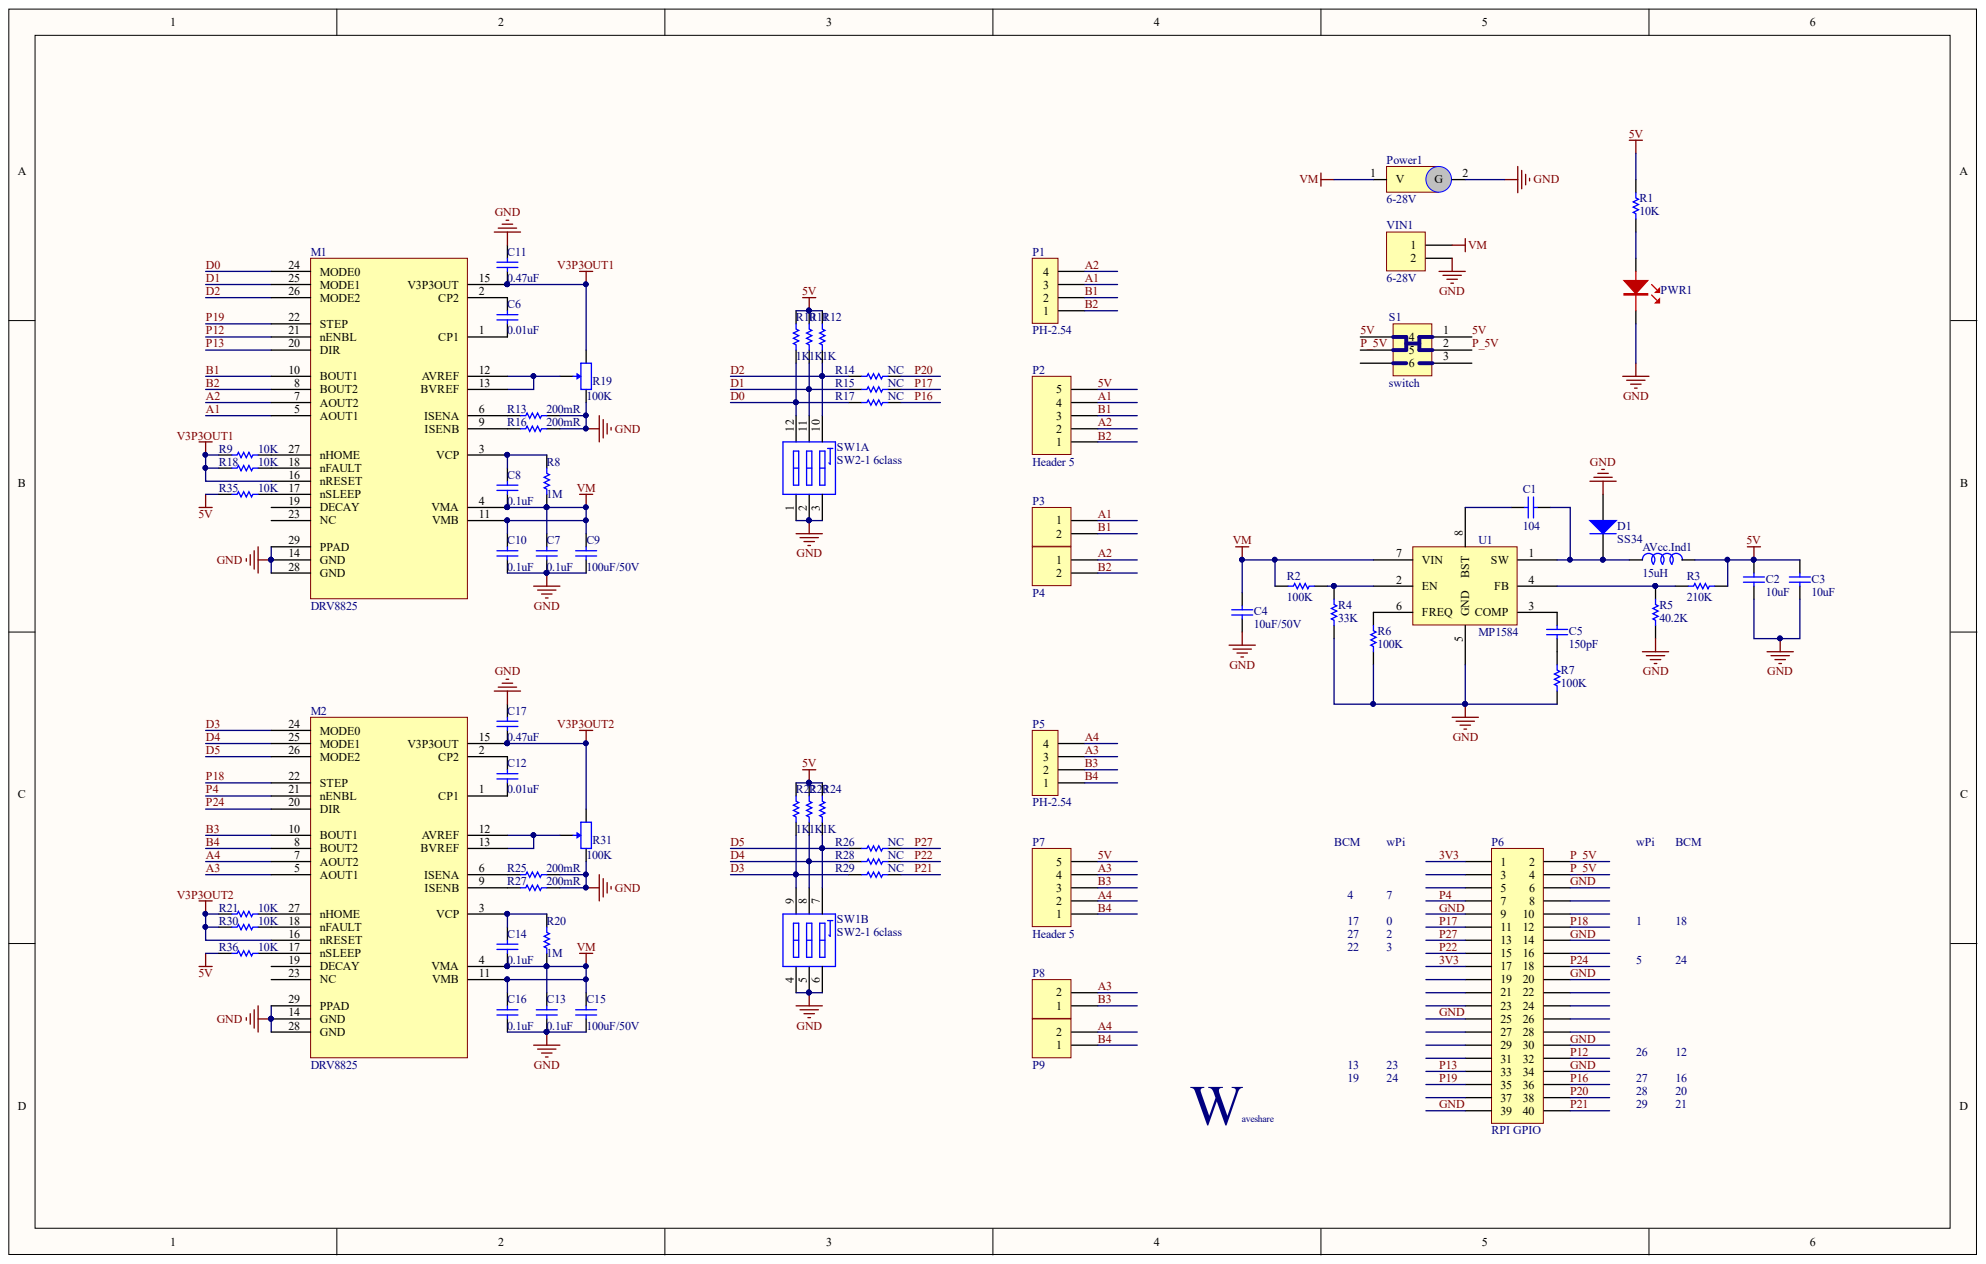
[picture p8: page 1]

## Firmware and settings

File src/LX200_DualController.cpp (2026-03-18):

/*
 * Project:    LX200 Focuser Automation
 * Component:  Dual Controller with Preset Management
 * File:       LX200_DualController.cpp
 * Author:     Robert D. Steele
 * Date:       2026-02-24
 * Version:    4.11 (Changes to add button control)
 * Copyright (c) 2026 Robert D. Steele. All Rights Reserved.
 */

#include <sys/select.h> // For non-blocking input
#include <termios.h>    // For terminal control
#include <unistd.h>
#include <iostream>
#include <fstream>
#include <vector>
#include <string>
#include <iomanip>
#include <signal.h>
#include <ctime>
#include "WaveShareStepper.hpp"
#include "config.h"
#include <cstdio> // Required for STDIN_FILENO
#include "AlpacaServer.hpp" // Add this include
#include <chrono>

struct Preset {
    std::string name;
    long long focPos;
    long long rotPos;
};

std::vector<Preset> g_presets;
WaveShareStepper* g_foc = nullptr;
WaveShareStepper* g_rot = nullptr;

struct ButtonState {
    int pin;
    bool isPressed;
    std::chrono::steady_clock::time_point pressStartTime;
};

// Initialize states
ButtonState btnFocIn  = {BTN_FOC_IN,  false};
ButtonState btnFocOut = {BTN_FOC_OUT, false};
ButtonState btnRotCW  = {BTN_ROT_CW,  false};
ButtonState btnRotCCW = {BTN_ROT_CCW, false};

// --- UTILITIES ---

// Helper: Checks if a key has been pressed without waiting for 'Enter'
bool kbhit() {
    struct timeval tv = {0L, 0L};
    fd_set fds;
    FD_ZERO(&fds);
    FD_SET(0, &fds);
    return select(1, &fds, NULL, NULL, &tv) > 0;
}

#include <chrono>

void handlePhysicalButtons(WaveShareStepper* foc, WaveShareStepper* rot) {
    // Persistent state for ramping logic
    static auto focInStart = std::chrono::steady_clock::now();
    static auto focOutStart = std::chrono::steady_clock::now();
    static auto rotCWStart = std::chrono::steady_clock::now();
    static auto rotCCWStart = std::chrono::steady_clock::now();

    static bool focInActive = false;
    static bool focOutActive = false;
    static bool rotCWActive = false;
    static bool rotCCWActive = false;

    // --- FOCUSER IN (GPIO 17) ---
    if (gpioRead(BTN_FOC_IN) == 0) {
        if (!focInActive) { focInActive = true; focInStart = std::chrono::steady_clock::now(); }
        auto held = std::chrono::duration_cast<std::chrono::seconds>(std::chrono::steady_clock::now() - focInStart).count();
        int speed = (held < RAMP_THRESHOLD_SEC) ? FOC_SPEED_SLOW : FOC_SPEED_MAX;
        foc->moveStepsRamped(20, speed, 0, CCW); 
    } else { focInActive = false; }

    // --- FOCUSER OUT (GPIO 27) ---
    if (gpioRead(BTN_FOC_OUT) == 0) {
        if (!focOutActive) { focOutActive = true; focOutStart = std::chrono::steady_clock::now(); }
        auto held = std::chrono::duration_cast<std::chrono::seconds>(std::chrono::steady_clock::now() - focOutStart).count();
        int speed = (held < RAMP_THRESHOLD_SEC) ? FOC_SPEED_SLOW : FOC_SPEED_MAX;
        foc->moveStepsRamped(20, speed, 0, CW);
    } else { focOutActive = false; }

    // --- ROTATOR CW (GPIO 22) ---
    if (gpioRead(BTN_ROT_CW) == 0) {
        if (!rotCWActive) { rotCWActive = true; rotCWStart = std::chrono::steady_clock::now(); }
        auto held = std::chrono::duration_cast<std::chrono::seconds>(std::chrono::steady_clock::now() - rotCWStart).count();
        int speed = (held < RAMP_THRESHOLD_SEC) ? ROT_SPEED_SLOW : ROT_SPEED_MAX;
        rot->moveStepsRamped(10, speed, 0, CW);
    } else { rotCWActive = false; }

    // --- ROTATOR CCW (GPIO 23) ---
    if (gpioRead(BTN_ROT_CCW) == 0) {
        if (!rotCCWActive) { rotCCWActive = true; rotCCWStart = std::chrono::steady_clock::now(); }
        auto held = std::chrono::duration_cast<std::chrono::seconds>(std::chrono::steady_clock::now() - rotCCWStart).count();
        int speed = (held < RAMP_THRESHOLD_SEC) ? ROT_SPEED_SLOW : ROT_SPEED_MAX;
        rot->moveStepsRamped(10, speed, 0, CCW);
    } else { rotCCWActive = false; }
}

void clearLog() {
    std::cout << "Are you sure you want to delete all night_log.txt entries? (y/N): ";
    char confirm;
    std::cin >> confirm;
    if (tolower(confirm) == 'y') {
        std::ofstream logFile("night_log.txt", std::ios::trunc); // 'trunc' wipes the file
        if (logFile.is_open()) {
            std::cout << "[INFO] Log file cleared." << std::endl;
            logFile.close();
        }
    } else {
        std::cout << "[INFO] Operation cancelled." << std::endl;
    }
}

void logSession(long long fPos, long long rPos) {
    std::ofstream logFile("night_log.txt", std::ios_base::app);
    if (logFile.is_open()) {
        std::time_t now = std::time(nullptr);
        char ts[20];
        std::strftime(ts, sizeof(ts), "%Y-%m-%d %H:%M", std::localtime(&now));
        logFile << "[" << ts << "] Foc: " << std::setw(8) << fPos 
                << " | Rot: " << std::setw(8) << rPos << "\n";
        std::cout << "[LOG] Session data saved to night_log.txt" << std::endl;
    }
}

void viewLog() {
    std::ifstream logFile("night_log.txt");
    if (!logFile.is_open()) {
        std::cout << "[ERROR] No log file found yet." << std::endl;
        return;
    }
    std::string line;
    std::vector<std::string> lines;
    while (std::getline(logFile, line)) {
        lines.push_back(line);
    }
    
    std::cout << "\n--- RECENT SESSION LOGS (Last 10) ---" << std::endl;
    int start = (lines.size() > 10) ? lines.size() - 10 : 0;
    for (size_t i = start; i < lines.size(); ++i) {
        std::cout << lines[i] << std::endl;
    }
    std::cout << "--------------------------------------" << std::endl;
    logFile.close();
}

void loadPresets() {
    g_presets.clear();
    std::ifstream file("presets.txt");
    std::string n; long long f, r;
    while (file >> n >> f >> r) g_presets.push_back({n, f, r});
}

void savePresets() {
    std::ofstream file("presets.txt");
    for (const auto& p : g_presets) file << p.name << " " << p.focPos << " " << p.rotPos << "\n";
}

void safety_shutdown(int sig) {
    std::cout << "\n[HALT] Emergency Stop Triggered." << std::endl;
    if (g_foc) g_foc->setPower(false);
    if (g_rot) g_rot->setPower(false);
    gpioTerminate();
    exit(0);
}

// --- UI ---
void printMenu(long long fPos, long long rPos) {
    // Progress calculation for the dashboard
    double fPct = (double)(fPos - FOC_LIMIT_MIN) / (FOC_LIMIT_MAX - FOC_LIMIT_MIN) * 100.0;
    double rPct = (double)(rPos - ROT_LIMIT_MIN) / (ROT_LIMIT_MAX - ROT_LIMIT_MIN) * 100.0;

    std::cout << "\n=================== SYSTEM STATUS ======================" << std::endl;
    std::cout << " FOCUSER: " << std::setw(8) << fPos << " steps [" << std::fixed << std::setprecision(1) << fPct << "% Travel]" << std::endl;
    std::cout << " ROTATOR: " << std::setw(8) << rPos << " steps [" << std::fixed << std::setprecision(1) << rPct << "% Travel]" << std::endl;
    std::cout << "--------------------------------------------------------" << std::endl;
    std::cout << " FOCUSER: [1-3] IN (0.1, 1, 5 Rev) | [4-6] OUT" << std::endl;
    std::cout << " ROTATOR: [7] 1/16 CW | [8] 1/16 CCW" << std::endl;
    std::cout << " PRESETS: [V] View/Apply | [K] Keep Current | [Y] Sync" << std::endl;
    std::cout << " UTILS:   [G] GoTo  | [M] Move  | [R] Re-Seat | [L] Log | [C] Clear Log" << std::endl;
    std::cout << " POWER:   [U] Unlock Motors (Release Holding Torque)" << std::endl; // Add this line
    std::cout << " EXIT:    [P] Park & Log | [Q] Quit" << std::endl;
    std::cout << "--------------------------------------------------------" << std::endl;
    std::cout << " Selection: ";
}

int main() {
    if (gpioInitialise() < 0) return 1;
    signal(SIGINT, safety_shutdown);

    // --- GPIO SETUP FOR BUTTONS ---
    int buttons[] = {BTN_FOC_IN, BTN_FOC_OUT, BTN_ROT_CW, BTN_ROT_CCW};
    for (int btn : buttons) {
      gpioSetMode(btn, PI_INPUT);
      gpioSetPullUpDown(btn, PI_PUD_UP); // Enable internal pull-up resistors
    }
    
    loadPresets();
    
    WaveShareStepper focuser(MOTOR_1);
    WaveShareStepper rotator(MOTOR_2);
    
    focuser.setLimits(FOC_LIMIT_MIN, FOC_LIMIT_MAX);
    rotator.setLimits(ROT_LIMIT_MIN, ROT_LIMIT_MAX);
    
    g_foc = &focuser; g_rot = &rotator;
    
    AlpacaServer alpaca(&focuser, &rotator);
    alpaca.start(8080); 
    
    // Check if we are interactive or a background service
    bool isInteractive = isatty(STDIN_FILENO);

    if (isInteractive) {
        printMenu(focuser.getCurrentPosition(), rotator.getCurrentPosition());
    } else {
        std::cout << "[SYSTEM] No terminal detected. Running in Background Service Mode." << std::endl;
    }

    while (true) {
        // 1. THE WATCHDOG: Always runs (even in service mode)
        focuser.checkTimeout();
        rotator.checkTimeout();
	
	// 2. Process Hardware Buttons

	handlePhysicalButtons (&focuser, &rotator);

        // 3. THE INPUT CHECK: Only if interactive
        if (isInteractive) {
            if (kbhit()) {
                char choice;
                if (!(std::cin >> choice)) {
                    isInteractive = false; 
                } else {
                    switch (toupper(choice)) {
                        case 'Q': 
                            alpaca.stop();
                            gpioTerminate();
                            return 0;

                        case '1': focuser.moveStepsRamped(STEPS_PER_KNOB_REV * 0.1, FOC_SPEED_MED, 500, CCW); break;
                        case '2': focuser.moveStepsRamped(STEPS_PER_KNOB_REV * 1.0, FOC_SPEED_MAX, 800, CCW); break;
                        case '3': focuser.moveStepsRamped(STEPS_PER_KNOB_REV * 5.0, FOC_SPEED_MAX, 800, CCW); break;
                        case '4': focuser.moveStepsRamped(STEPS_PER_KNOB_REV * 0.1, FOC_SPEED_MED, 500, CW); break;
                        case '5': focuser.moveStepsRamped(STEPS_PER_KNOB_REV * 1.0, FOC_SPEED_MAX, 800, CW); break;
                        case '6': focuser.moveStepsRamped(STEPS_PER_KNOB_REV * 5.0, FOC_SPEED_MAX, 800, CW); break;
                        case '7': rotator.moveStepsRamped(STEPS_PER_REV / 16, ROT_SPEED_MED, 400, CW); break;
                        case '8': rotator.moveStepsRamped(STEPS_PER_REV / 16, ROT_SPEED_MED, 400, CCW); break;
                        case 'C': clearLog(); break;
                        case 'L': viewLog(); break;

                        case 'R': { 
                            std::cout << "\n[RE-SEAT] Starting backlash normalization..." << std::endl;
                            focuser.reSeat(FOC_SPEED_MED);
                            break;
                        }

                        case 'V': {
                            if (g_presets.empty()) { std::cout << "No presets." << std::endl; break; }
                            for (size_t i=0; i < g_presets.size(); ++i) 
                                std::cout << "[" << i << "] " << g_presets[i].name << std::endl;
                            int idx; std::cout << "Select Index: "; std::cin >> idx;
                            if (idx >= 0 && (size_t)idx < g_presets.size()) {
                                rotator.moveTo(g_presets[idx].rotPos, ROT_SPEED_MED);
                                focuser.moveTo(g_presets[idx].focPos, FOC_SPEED_MED);
                            }
                            break;
                        }

                        case 'K': {
                            std::string n; std::cout << "Name: "; std::cin >> n;
                            g_presets.push_back({n, focuser.getCurrentPosition(), rotator.getCurrentPosition()});
                            savePresets(); break;
                        }

                        case 'Y': { 
                            int motor;
                            long long newPos;
                            std::cout << "\n[SYNC] Motor ([1] Focuser | [2] Rotator): ";
                            if (!(std::cin >> motor)) { std::cin.clear(); std::cin.ignore(100, '\n'); break; }
                            std::cout << "Enter position to sync to: ";
                            if (!(std::cin >> newPos)) { std::cin.clear(); std::cin.ignore(100, '\n'); break; }
                            
                            if (motor == 1) focuser.syncPosition(newPos);
                            else if (motor == 2) rotator.syncPosition(newPos);
                            std::cout << "[OK] Synced." << std::endl;
                            break;
                        }

                        case 'P': 
			    std::cout << "\n[SYSTEM] Commencing Secure Park..." << std::endl;
			    logSession(focuser.getCurrentPosition(), rotator.getCurrentPosition());
			  
			    // 1. Move Rotator to neutral center
			    rotator.moveTo(0, ROT_SPEED_MED); 
			  
			    // 2. Move Focuser to Rearward storage position (50,000 steps)
			    focuser.moveTo(FOC_LIMIT_MAX, FOC_SPEED_MED); 
			  
			    // 3. Immediately cut power (don't wait for the 30s watchdog)
			    focuser.setPower(false);
			    rotator.setPower(false);
			  
			    std::cout << "[SYSTEM] Motors parked and unlocked for storage." << std::endl;
			    break;

                        case 'G': { 
                            int motor; long long target;
                            std::cout << "\n[GOTO] Motor ([1] Focuser | [2] Rotator): ";
                            if (!(std::cin >> motor)) { std::cin.clear(); std::cin.ignore(100, '\n'); break; }
                            std::cout << "Enter Target Position: ";
                            if (!(std::cin >> target)) { std::cin.clear(); std::cin.ignore(100, '\n'); break; }
                            if (motor == 1) focuser.moveTo(target, FOC_SPEED_MED);
                            else if (motor == 2) rotator.moveTo(target, ROT_SPEED_MED);
                            break;
                        }

                        case 'M': { 
                            int motor; long long offset;
                            std::cout << "\n[MOVE] Motor ([1] Focuser | [2] Rotator): "; 
                            if (!(std::cin >> motor)) { std::cin.clear(); std::cin.ignore(100, '\n'); break; }
                            std::cout << "Enter Step Offset: ";
                            if (!(std::cin >> offset)) { std::cin.clear(); std::cin.ignore(100, '\n'); break; }
                            if (motor == 1) focuser.moveTo(focuser.getCurrentPosition() + offset, FOC_SPEED_MED);
                            else if (motor == 2) rotator.moveTo(rotator.getCurrentPosition() + offset, ROT_SPEED_MED);
                            break;
                        }

                        case 'U': { 
                            focuser.setPower(false);
                            rotator.setPower(false);
                            break;
                        }

                        default:
                            std::cout << "\n[!] Invalid choice." << std::endl;
                            break;
                    } // End switch
                    
                    printMenu(focuser.getCurrentPosition(), rotator.getCurrentPosition());
                } // End choice read check
            } // End kbhit
        } // End isInteractive

        // 3. HEARTBEAT (50ms delay)
	//    For the button logic that is begin added this usleep  was reduced
	//    from 100000 (100ms) to 50000 (50ms) for smooter button response
        usleep(50000); 
    } // End while(true)

    return 0;
}

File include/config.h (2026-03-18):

/*
 * Project:    LX200 Focuser Automation
 * Component:  System Configuration Constants
 * File:       config.h
 * Author:     Robert D. Steele
 * Date:       2026-02-23
 * Version:    3.9 (Added in pins for button control)
 * Copyright (c) 2026 Robert D. Steele. All Rights Reserved.
 */

#ifndef CONFIG_H
#define CONFIG_H

// --- HARDWARE SETTINGS (1/16 Microstepping) ---
// Calibrated against the actually hardware where 5 commanded turns
// turned into 6 3/4
const int STEPS_PER_REV = 3200;         // 200 * 16
const int DEFAULT_RAMP_MS = 800;
const int STEPS_PER_KNOB_REV = 2480; // changing based on hardware

/*
 * FOC_LIMIT_MIN was -50000. Gemini is recommending it be 0
 * which I'll do for now.
 */

// --- FOCUSER LIMITS (Adjust these based on your specific scope) ---
const long long FOC_LIMIT_MIN = 0;
const long long FOC_LIMIT_MAX = 50000;   // Example: 15.6 revs outward

// --- ROTATOR LIMITS (Prevents cable wrap) ---
const long long ROT_LIMIT_MIN = -6400;   // 2 full turns left
const long long ROT_LIMIT_MAX = 6400;    // 2 full turns right

// --- FOCUSER (M1) - Delays doubled from v3.2 to keep velocity ---
const int FOC_SPEED_MAX  = 600;          
const int FOC_SPEED_MED  = 1200;         
const int FOC_SPEED_SLOW = 2000;         
const int FOC_BACKLASH   = 600;          // Halved for 1/16 resolution
const int FOC_PREF_DIR   = 0;   // 1 for CW, 0 for CCW

// --- ROTATOR (M2) - Delays doubled from v3.2 ---
const int ROT_SPEED_MAX  = 1600;
const int ROT_SPEED_MED  = 2400;
const int ROT_SPEED_SLOW = 5000;
const int ROT_BACKLASH   = 200;          // Halved
const int ROT_PREF_DIR   = 1; 

// --- BUTTON BOX PINS (GPIO Numbers) ---
const int BTN_FOC_IN  = 17; // Pin 11
const int BTN_FOC_OUT = 27; // Pin 13
const int BTN_ROT_CW  = 22; // Pin 15
const int BTN_ROT_CCW = 23; // Pin 16

// --- RAMPING LOGIC ---
const double RAMP_THRESHOLD_SEC = 2.0; // Seconds before switching to high speed

#define RESEAT_GAP_STEPS 1000  // Adjust this based on how much 'slop' your gears have

#endif

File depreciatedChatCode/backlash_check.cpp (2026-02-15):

#include <iostream>
#include <string>
#include "WaveShareStepper.hpp"

// Helper to clear input buffer
void clearInput() {
    std::cin.ignore(10000, '\n');
}

int main() {
    if (gpioInitialise() < 0) return 1;

    {
        WaveShareStepper motor(MOTOR_1); 
        motor.setPower(true);

        int steps_per_rev = 3200; // Assuming 1/16 microstepping
        int test_distance = 1000; // A decent move to clear all mechanical slop

        std::cout << "--- SCT Precision Backlash Tool ---" << std::endl;
        
        // PHASE 1: PRE-TENSION
        // We move CW first just to tighten everything against gravity/gears
        std::cout << "1. Tensioning the system (Moving CW 100 steps)..." << std::endl;
        motor.moveSteps(100, 200, CW); // Slow, deliberate move
        
        std::cout << "   SYSTEM TENSIONED." << std::endl;
        std::cout << "2. Mark your ZERO line on the pulley/belt now." << std::endl;
        std::cout << "   Press ENTER to start the test move..." << std::endl;
        std::cin.get();

        // PHASE 2: THE EXCURSION
        std::cout << "3. Moving OUT " << test_distance << " steps..." << std::endl;
        motor.moveSteps(test_distance, 400, CW);
        
        std::cout << "4. Moving BACK " << test_distance << " steps..." << std::endl;
        motor.moveSteps(test_distance, 400, CCW);

        // PHASE 3: THE INTERACTIVE MEASUREMENT
        std::cout << "\n--- MEASUREMENT PHASE ---" << std::endl;
        std::cout << "Look at your mark. Is it perfectly aligned?" << std::endl;
        std::cout << "Controls:" << std::endl;
        std::cout << "  [+] : Nudge CW 1 step" << std::endl;
        std::cout << "  [-] : Nudge CCW 1 step" << std::endl;
        std::cout << "  [f] : Nudge CW 10 steps (Fast)" << std::endl;
        std::cout << "  [b] : Nudge CCW 10 steps (Back)" << std::endl;
        std::cout << "  [q] : Quit and calculate" << std::endl;

        int correction_steps = 0;
        char input;
        bool measuring = true;

        while (measuring) {
            std::cout << "Current Correction: " << correction_steps << " steps. Command: ";
            std::cin >> input;

            switch(input) {
                case '+':
                    motor.moveSteps(1, 500, CW);
                    correction_steps++;
                    break;
                case '-':
                    motor.moveSteps(1, 500, CCW);
                    correction_steps--;
                    break;
                case 'f':
                    motor.moveSteps(10, 500, CW);
                    correction_steps += 10;
                    break;
                case 'b':
                    motor.moveSteps(10, 500, CCW);
                    correction_steps -= 10;
                    break;
                case 'q':
                    measuring = false;
                    break;
                default:
                    std::cout << "Invalid. Use +, -, f, b, or q." << std::endl;
            }
        }

        std::cout << "\n--- RESULTS ---" << std::endl;
        std::cout << "Mechanical Backlash: " << std::abs(correction_steps) << " steps." << std::endl;
        std::cout << "Enter this value into NINA's 'Backlash Compensation' (Overshoot Method)." << std::endl;

        motor.setPower(false);
    }

    gpioTerminate();
    return 0;
}

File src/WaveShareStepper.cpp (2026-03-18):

/*
 * Project:    LX200 Focuser Automation
 * Component:  WaveShare Stepper Driver Implementation
 * File:       WaveShareStepper.cpp
 * Author:     Robert D. Steele
 * Date:       2026-02-23
 * Version:    3.5 (Fixed halt command)
 * Copyright (c) 2026 Robert D. Steele. All Rights Reserved.
 */

#include "WaveShareStepper.hpp"
#include "config.h"
#include <iostream>
#include <fstream>
#include <cmath>
#include <algorithm>
#include <unistd.h>

/*
 * Rob changing the en/dir/step definition back to the ones used for
 * 24ac681 commit.
 *
 * The ones used for the recent version written by Gemini.
 *   Motor 1: _en =  4; _dir = 23; _step = 18;
 *   Motor 2: _en = 17; _dir = 27; _step = 22;
 *
 * The ones that are working for me:
 *   Motor 1: _en = 12; _dir = 13; _step = 19;
 *   Motor 2: _en =  4; _dir = 24; _step = 18;
 */


WaveShareStepper::WaveShareStepper(MotorChannel channel) : _channel(channel), _isPowered(false) {
    if (channel == MOTOR_1) {
        _en = 12; _dir = 13; _step = 19; 
        _backlash = FOC_BACKLASH;
        _prefDir = FOC_PREF_DIR;
        _limitMin = FOC_LIMIT_MIN;
        _limitMax = FOC_LIMIT_MAX;
    } else { 
        _en = 4; _dir = 24; _step = 18; 
        _backlash = ROT_BACKLASH;
        _prefDir = ROT_PREF_DIR;
        _limitMin = ROT_LIMIT_MIN;
        _limitMax = ROT_LIMIT_MAX;
    }

    gpioSetMode(_en, PI_OUTPUT);
    gpioSetMode(_dir, PI_OUTPUT);
    gpioSetMode(_step, PI_OUTPUT);
    loadPosition();
    setPower(false);
    updateActivity();
}

WaveShareStepper::~WaveShareStepper() {
    setPower(false);
}

void WaveShareStepper::updateActivity() {
    _lastActivity = std::chrono::steady_clock::now();
}

void WaveShareStepper::setPower(bool on) {
  gpioWrite(_en, on ? 1 : 0);
  _isPowered = on;
  if (on) updateActivity(); // Reset timer when power is turned on
}

void WaveShareStepper::checkTimeout() {
  if (!_isPowered) return; // Already off, nothing to do
  
  auto now = std::chrono::steady_clock::now();
  auto elapsed = std::chrono::duration_cast<std::chrono::seconds>(now - _lastActivity).count();

    if (elapsed >= 30) {
        std::cout << "\n[POWER] Auto-Release: " << (_channel == MOTOR_1 ? "Focuser" : "Rotator") << " idling for 30s." << std::endl;
        setPower(false);
    }
}

// New version of moveStepsRamped created to include the 30s countdown timer
void WaveShareStepper::moveStepsRamped(long long steps, int maxSpeed, int rampMs, int dir) {

    _abortMove = false; // Reset the flag before starting
    
    if (!isMoveSafe(steps, dir)) return; 

    _isMoving = true; // <--- START
    
    setPower(true); // This also calls updateActivity()
    gpioWrite(_dir, (dir == CW) ? 1 : 0);

    for (long long i = 0; i < steps; i++) {

        // THE KILL SWITCH CHECK
        if (_abortMove) {
            std::cout << "[HALT] Aborting move mid-stream!" << std::endl;
            break; 
        }
	
        gpioWrite(_step, 1);
        gpioDelay(maxSpeed);
        gpioWrite(_step, 0);
        gpioDelay(maxSpeed);
        _stepPosition += (dir == CW) ? 1 : -1;
    }

    _isMoving = false; // <--- END
    
    updateActivity(); // Start the 30s countdown AFTER the move ends
    savePosition();
}

void WaveShareStepper::setLimits(long long minPos, long long maxPos) {
    _limitMin = minPos;
    _limitMax = maxPos;
}

bool WaveShareStepper::isMoveSafe(long long steps, int direction) {
    long long displacement = (direction == CW) ? steps : -steps;
    // FIX: Changed _currentPosition to _stepPosition
    long long targetPos = _stepPosition + displacement;

    if (targetPos < _limitMin || targetPos > _limitMax) {
        std::cerr << "[SAFETY] Move blocked! Target " << targetPos 
                  << " is outside limits (" << _limitMin << " to " << _limitMax << ")" << std::endl;
        return false;
    }
    return true;
}

void WaveShareStepper::reSeat(int speed) {
    setPower(true); // Engages motor and calls updateActivity()
    
    // Move CW then CCW
    moveStepsRamped(RESEAT_GAP_STEPS, speed, 400, CW);
    usleep(200000); 
    moveStepsRamped(RESEAT_GAP_STEPS, speed, 400, CCW);
    
    // Use your existing class function to reset the 30s timer
    updateActivity(); 
    
    std::cout << "[RE-SEAT] Mechanism normalized and timer reset." << std::endl;
}

void WaveShareStepper::moveTo(long long targetPosition, int speed) {
    // 1. Safety Clamp: Never allow a position lower than the defined Minimum (usually 0)
    if (targetPosition < _limitMin) {
        std::cout << "[SAFETY] Clamping negative/low target " << targetPosition 
                  << " to Min: " << _limitMin << std::endl;
        targetPosition = _limitMin;
    }

    // 2. Safety Clamp: Never allow a position higher than the defined Maximum
    if (targetPosition > _limitMax) {
        std::cout << "[LIMIT] Clamping high target " << targetPosition 
                  << " to Max: " << _limitMax << std::endl;
        targetPosition = _limitMax;
    }

    // 3. Calculate Delta from where we ARE to where we WANT to be
    long long delta = targetPosition - _stepPosition;
    
    // If we are already there, stop
    if (delta == 0) return;
    
    // 4. Determine direction and execute
    int dir = (delta > 0) ? CW : CCW;
    std::cout << "[MOTOR] Moving " << std::abs(delta) << " steps to reach position " << targetPosition << std::endl;
    
    moveStepsRamped(std::abs(delta), speed, DEFAULT_RAMP_MS, dir);
}

void WaveShareStepper::syncPosition(long long newPos) {
    _stepPosition = newPos;
    savePosition();
}

void WaveShareStepper::savePosition() {
    std::string filename = (_channel == MOTOR_1) ? "pos_m1.txt" : "pos_m2.txt";
    std::ofstream posFile(filename);
    if (posFile.is_open()) { posFile << _stepPosition; posFile.close(); }
}

void WaveShareStepper::loadPosition() {
    std::string filename = (_channel == MOTOR_1) ? "pos_m1.txt" : "pos_m2.txt";
    std::ifstream posFile(filename);
    if (posFile.is_open()) { posFile >> _stepPosition; posFile.close(); }
    else { _stepPosition = 0; }
}

void WaveShareStepper::halt() {
    _abortMove = true; 
}

void WaveShareStepper::park() {
  if (_channel == MOTOR_1) {
    // FOCUSER: Move to the Rearward position (Full CW / Max Steps)
    std::cout << "[PARK] Moving Focuser to Rearward storage position: " << _limitMax << std::endl;
    moveTo(_limitMax, FOC_SPEED_MED);
  } else {
    // ROTATOR: Move to Center (Step 0) to avoid cable tension
    std::cout << "[PARK] Centering Rotator to position 0..." << std::endl;
    moveTo(0, ROT_SPEED_MED);
  }
  
  // Crucial: Release power so the motors stay cool during storage
  setPower(false);
  std::cout << "[PARK] " << (_channel == MOTOR_1 ? "Focuser" : "Rotator") << " secured and powered down." << std::endl;
}

void WaveShareStepper::globalEmergencyStop(WaveShareStepper* instance) {
    if (instance) instance->setPower(false);
    gpioTerminate();
    exit(0);
}

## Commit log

2026-02-03 Code Rob modified to run both motors at 16 microsteps/step.
2026-02-03 Fixed a spelling error.
    [robMotor1Test.py, robMotor2Test.py]
2026-02-03 Updated README.md to reflect my current status.
2026-02-04 Working versions with english corrections in the DRV8825.py file.
    [DRV8825.py, robMotor1Test.py, robMotor2Test.py]
2026-02-09 Still working to get a C++ version that moves the motors. Waitinf for the resistors to be delivered.
2026-02-11 V0 does not work. V1 does but I wanted to track both for now.
    [stepper_rotate_v0.cpp, stepper_rotate_v1.cpp]
2026-02-11 Working version of cpp code as generated by Gemini. Somce more fixes are coming down the pike.
    [WaveShareStepper.cpp, main.cpp]
2026-02-11 Working motor 2 code.
2026-02-11 Working to move both both motors.
2026-02-11 Both motors are working.
2026-02-15 New version of backlash_check.cpp turned for a 10 inch LX200 scope.
    [backlash_check.cpp]
2026-02-19 Focus motor moving with ramped logic. Things are looking better and I don't want to lose these changes.
2026-02-19 New code to repalce StepperRotateV1.cpp
2026-02-20 Updated code running without real motors.
2026-02-21 All of the code is cureent broken and I'm attempt to get Gemini to help me fix it.
    [WaveShareStepper.cpp, ZeroFocuser.cpp]
2026-02-22 Non functioning code I am preserving for future editing and fixing.
    [HardwareProbe.cpp, Motor1Test.cpp, Motor2Test.cpp]
2026-02-23 Add link to Stepper Motor HAT documentation
2026-02-24 Working to get a stable version that works correctly.
    [DualMotorTest.cpp, LX200_FocuserControl.cpp, WaveShareStepper.cpp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]
2026-02-24 More fixes getting ready to test with real motors.
    [LX200_DualController.cpp, WaveShareStepper.cpp, config.h]
2026-02-24 More fixes from Gemini.
    [WaveShareStepper.cpp, config.h]
2026-02-24 Fixing more compile errors.
    [DualMotorTest.cpp, LX200_FocuserControl.cpp]
2026-02-24 Now moving the motors correctly since I changed the pin definitions..
    [WaveShareStepper.cpp]
2026-02-28 LX200 logic at least moving the motors.
2026-03-02 Version is not working - wrt Alapca Device Hub.
2026-03-03 vault backup: 2026-03-03 14:55:57
    [GT2-60ToothPulleyV09.scad, NEMA17_Bracket_Calibration_Gauge.scad, Nema17BracketV08.scad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]
2026-03-04 vault backup: 2026-03-03 16:24:41
    [AssemblyLX200FocuserBracket.step, GT2-60ToothPulleyV09.step]
2026-03-04 Renamed scadFiles directory to CadFiles
    [AssemblyLX200FocuserBracket.step, GT2-60ToothPulleyV09.scad, GT2-60ToothPulleyV09.step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]
2026-03-18 Added button logic that runs simultaniously to the NINA and ASCOM software.
